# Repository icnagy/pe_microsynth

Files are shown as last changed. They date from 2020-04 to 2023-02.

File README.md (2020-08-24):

# PE Microsynth / Clef B30

Redrawn in KiCad.

Practical Electronics June 1982
MICROSYNTH Part 1 by A.R. Bradford MSc page 18

Practical Electronics July 1982
MICROSYNTH Part 2 by A.R. Bradford MSc page 38

Practical Electronics August 1982
MICROSYNTH Part 3 by A.R.Bradford MSc page 36

## Schematics

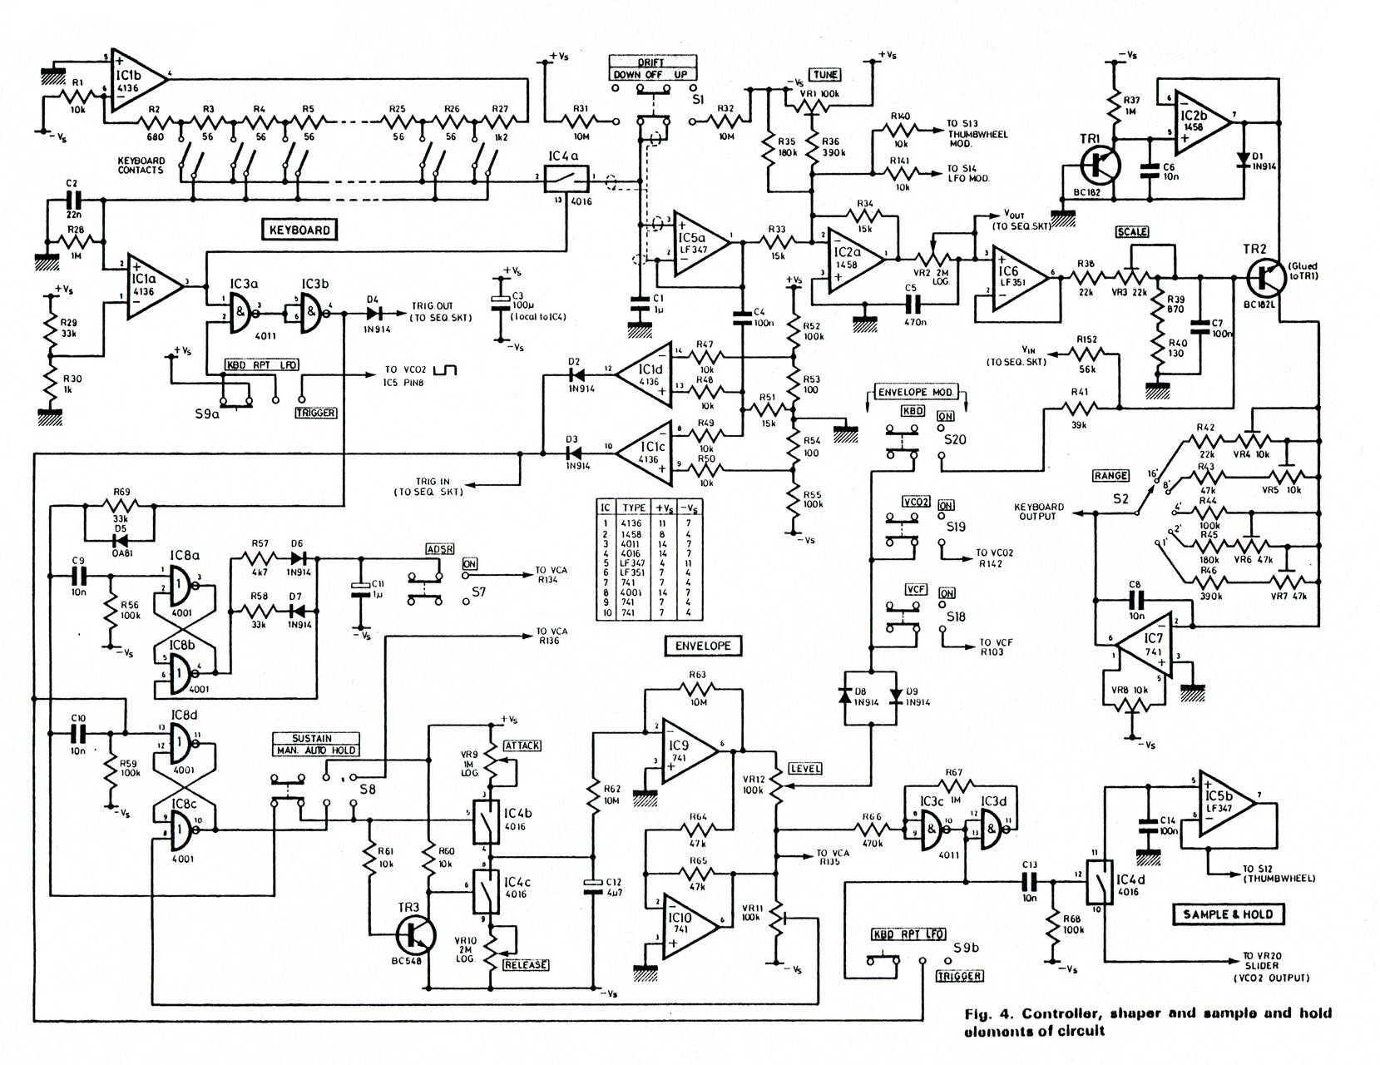
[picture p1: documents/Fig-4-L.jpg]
Figure 4. Controller, shaper and sample and hold elements of circuit

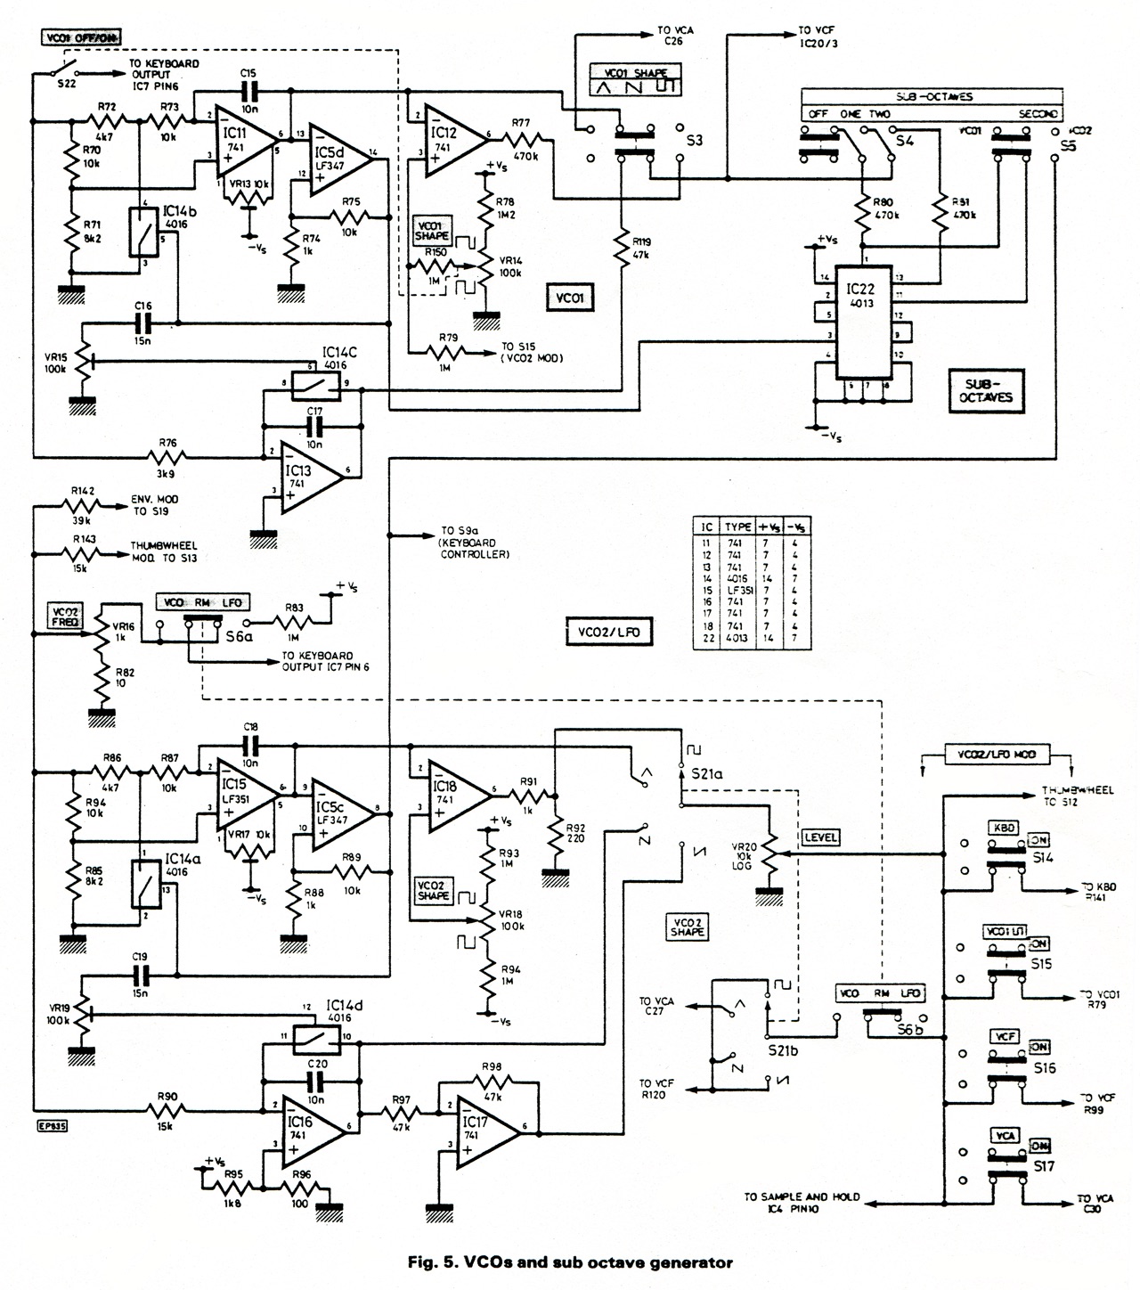
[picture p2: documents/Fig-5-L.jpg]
Figure 5. VCOs and sub octave generator

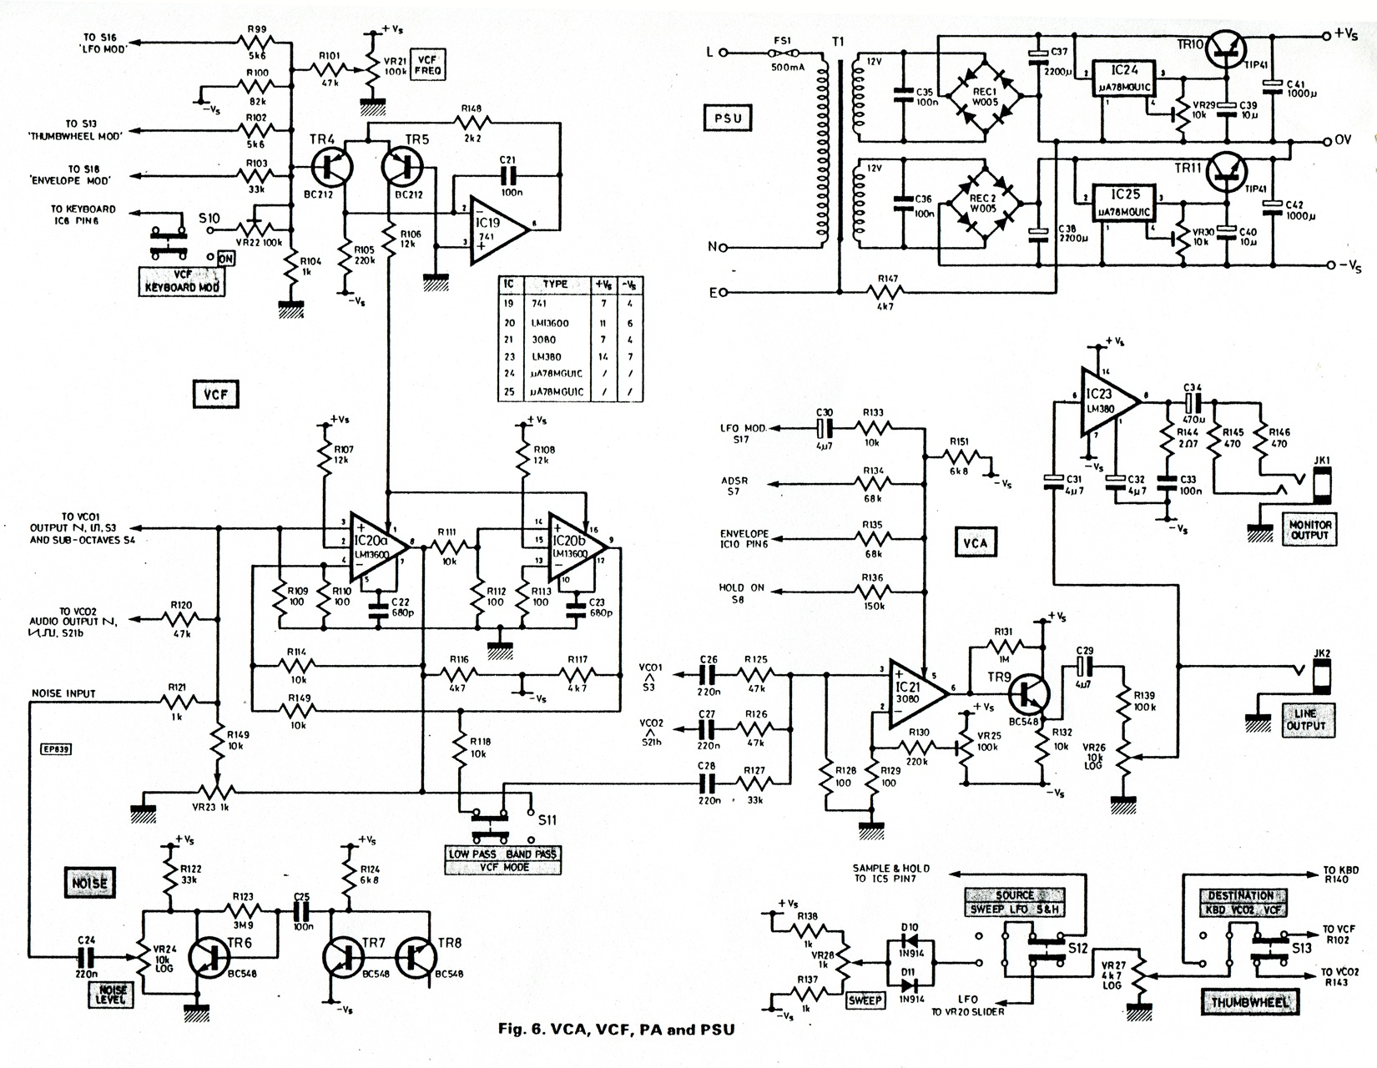
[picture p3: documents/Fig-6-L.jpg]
Figure 6. VCA, VCF, PA and PSU


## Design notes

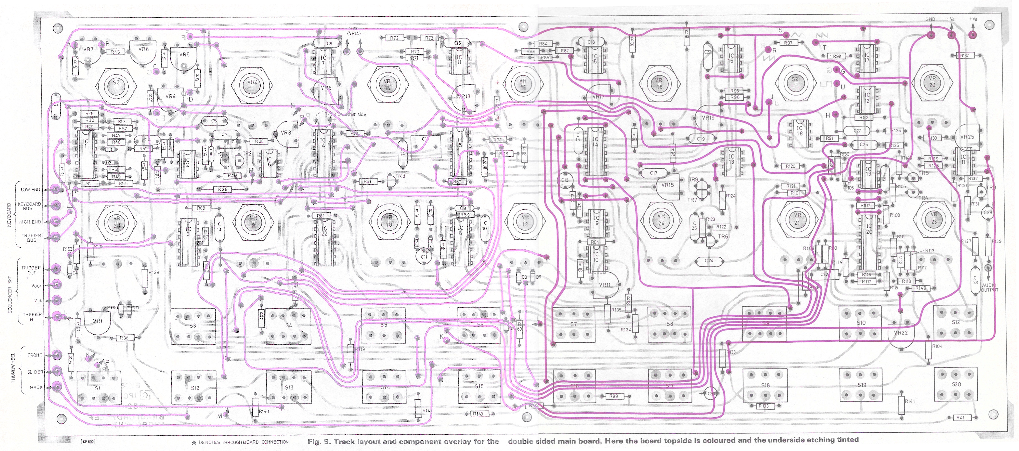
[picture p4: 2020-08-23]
documents/pe-micro-pcb.jpg

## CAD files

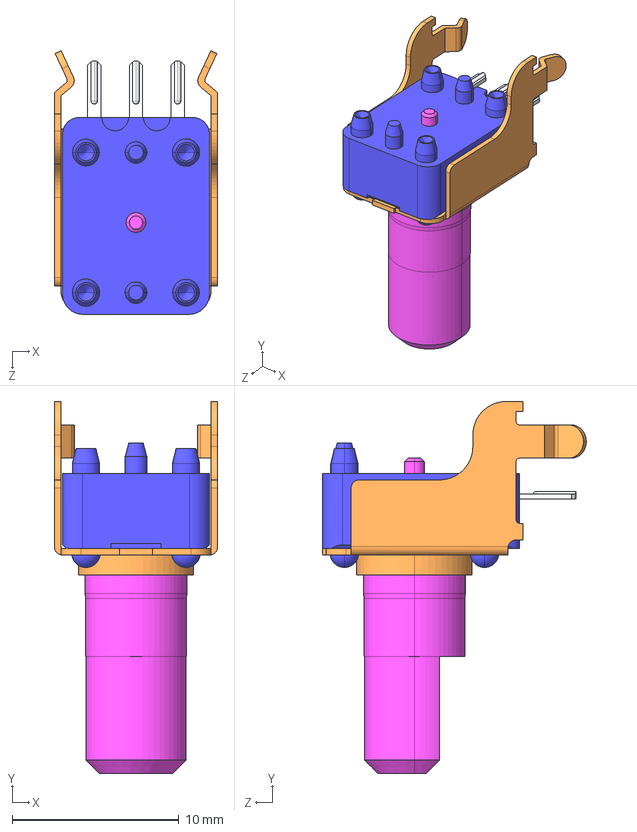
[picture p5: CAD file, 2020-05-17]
3dmodels/RK09K1110B1V.STEP
9.80 x 22.3 x 15.8 mm

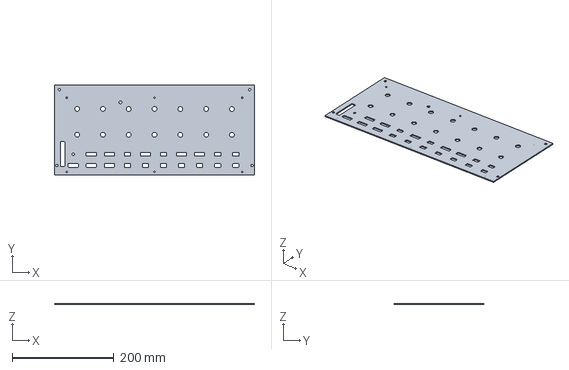
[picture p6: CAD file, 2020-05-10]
3dmodels/pe-microsynthv3.stp
393.7 x 177.8 x 2.00 mm

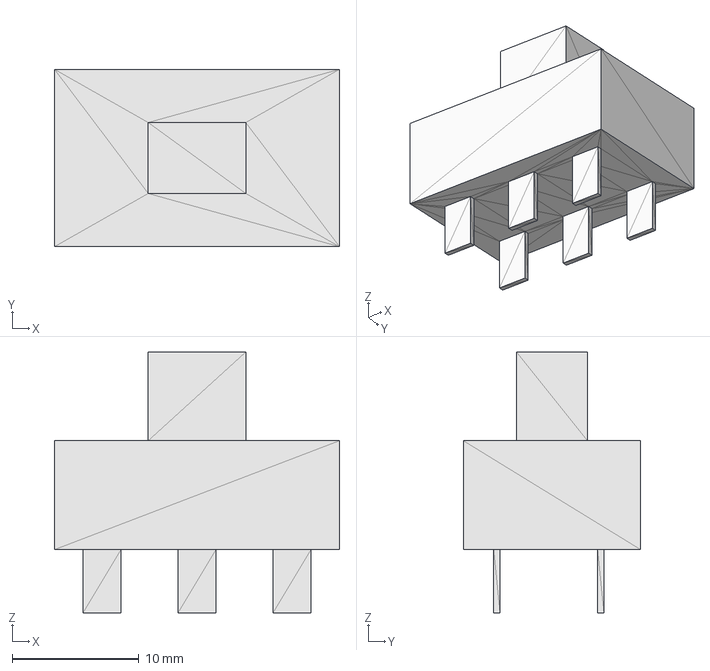
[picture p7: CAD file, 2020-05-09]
3dmodels/dpdt-tayda.step
22.5 x 14.0 x 20.6 mm

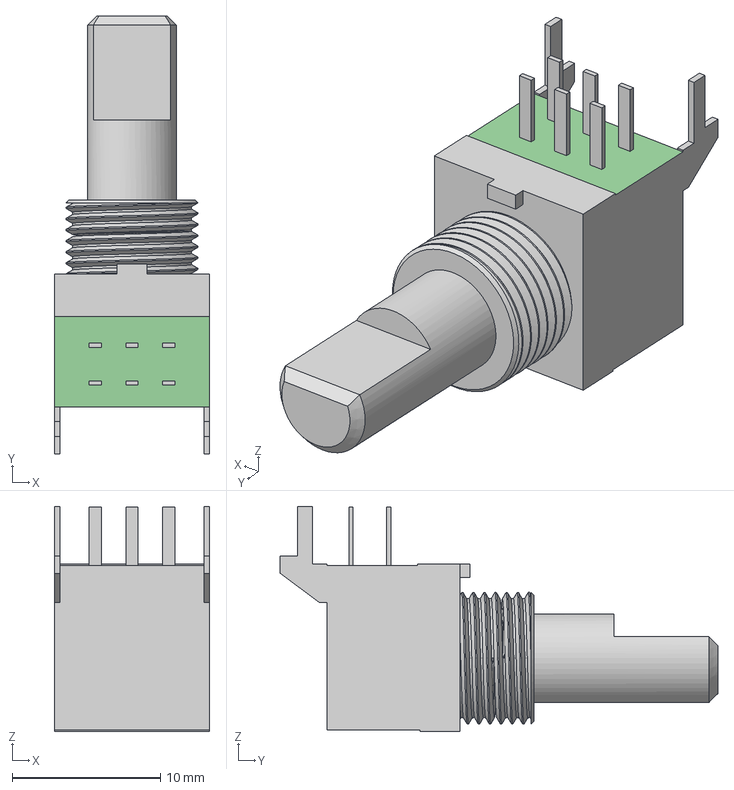
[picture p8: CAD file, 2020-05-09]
3dmodels/ALPS RK09L v3.step
10.5 x 29.6 x 15.2 mm

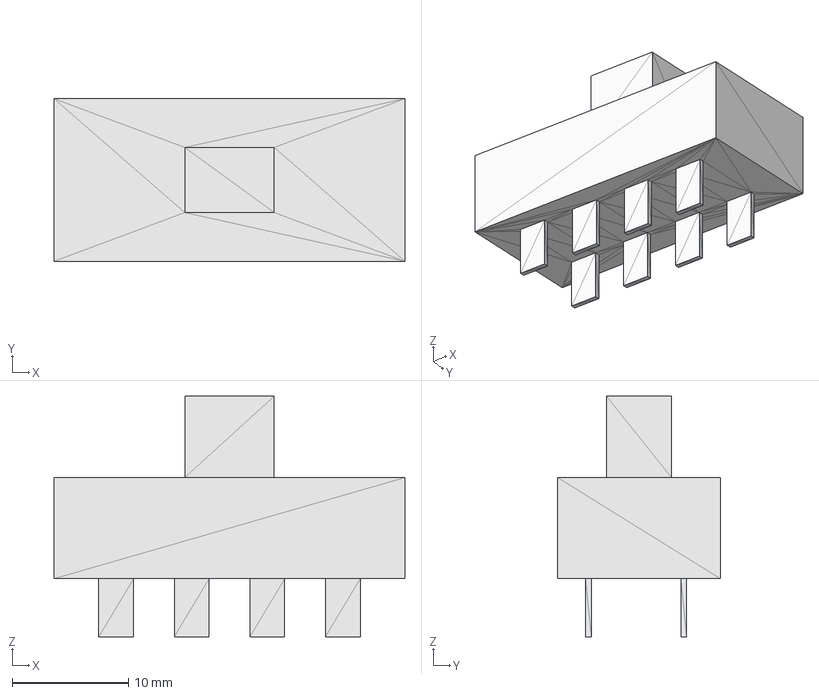
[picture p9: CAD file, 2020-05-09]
3dmodels/dp3t-tayda.step
30.2 x 14.0 x 20.7 mm

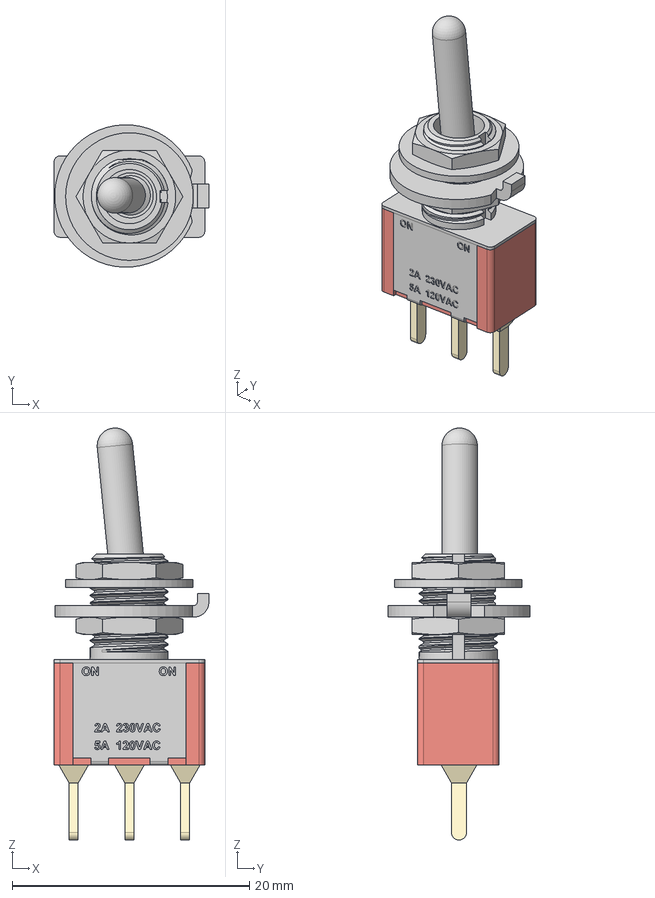
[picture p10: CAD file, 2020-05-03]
3dmodels/RS-PRO Schalter v5.step
13.1 x 12.0 x 34.7 mm
Hebel
Scheibe
Mutter
Scheibe (1)
Mutter (1)
Stifte
Gewinde

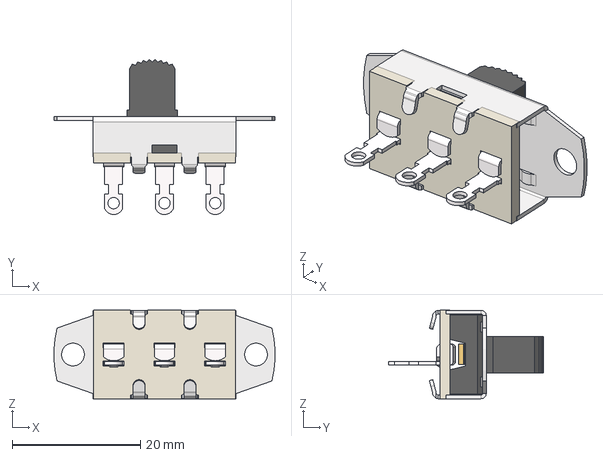
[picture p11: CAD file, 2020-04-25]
3dmodels/GF-624-6014_3D MODEL.stp
34.5 x 24.2 x 13.8 mm

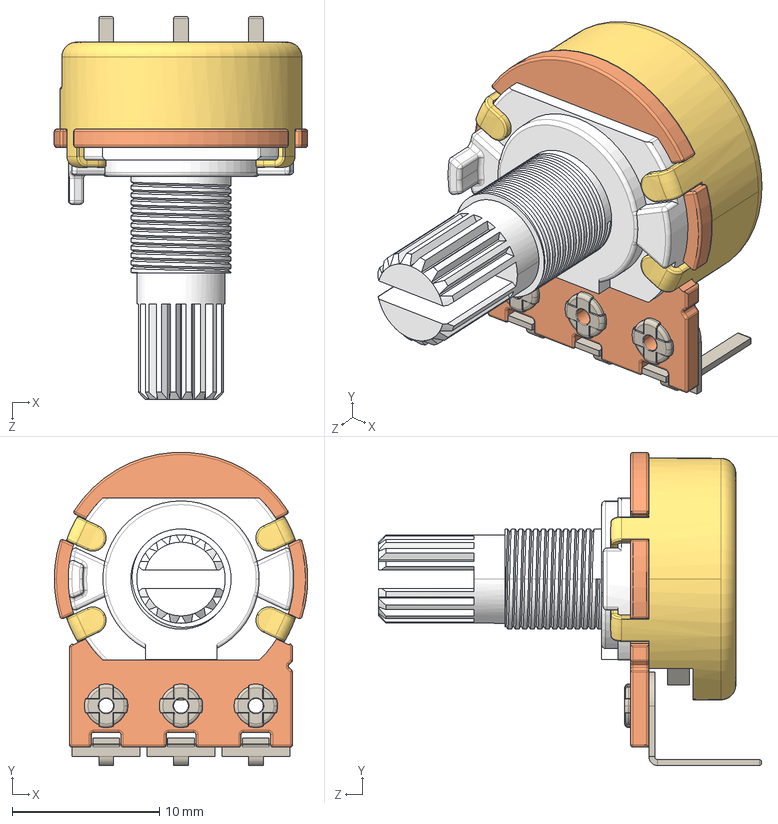
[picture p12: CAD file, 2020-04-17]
3dmodels/Standard Potentiometer - Vertical (No Value).STEP
17.2 x 21.2 x 26.0 mm

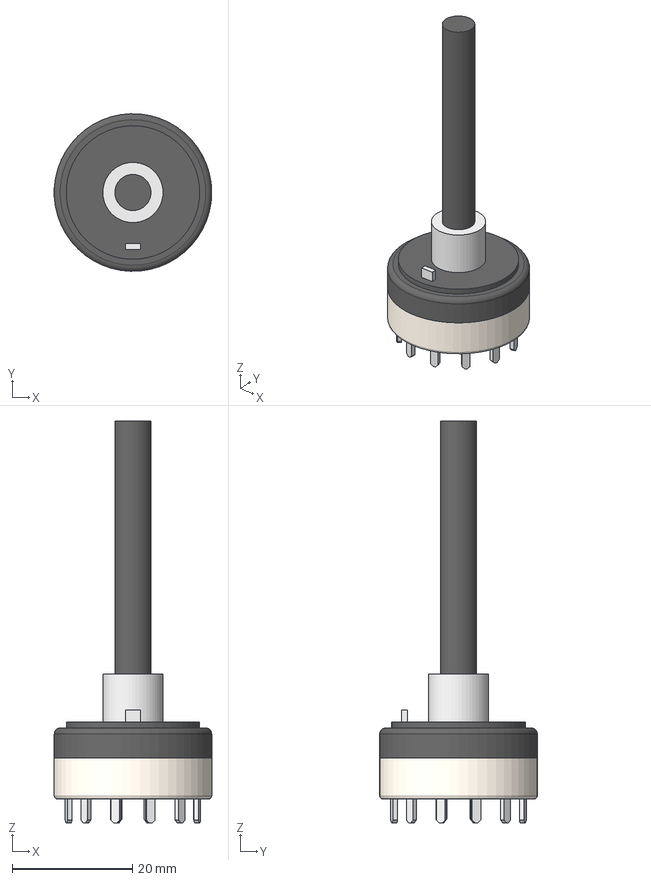
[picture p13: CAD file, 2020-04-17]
3dmodels/Stufenschalter 2x6.step
26.2 x 26.2 x 66.8 mm
Sketch
Circle
Zylinder003
Zylinder004
Zylinder002
Würfel

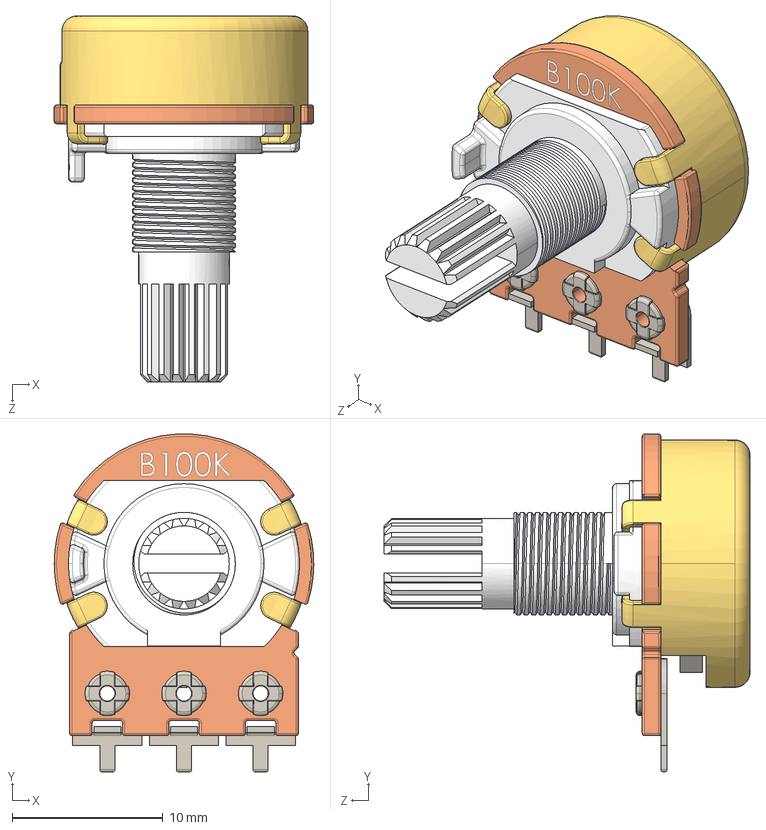
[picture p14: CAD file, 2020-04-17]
3dmodels/Standard Potentiometer - Horizontal (100K).STEP
17.2 x 22.4 x 24.3 mm

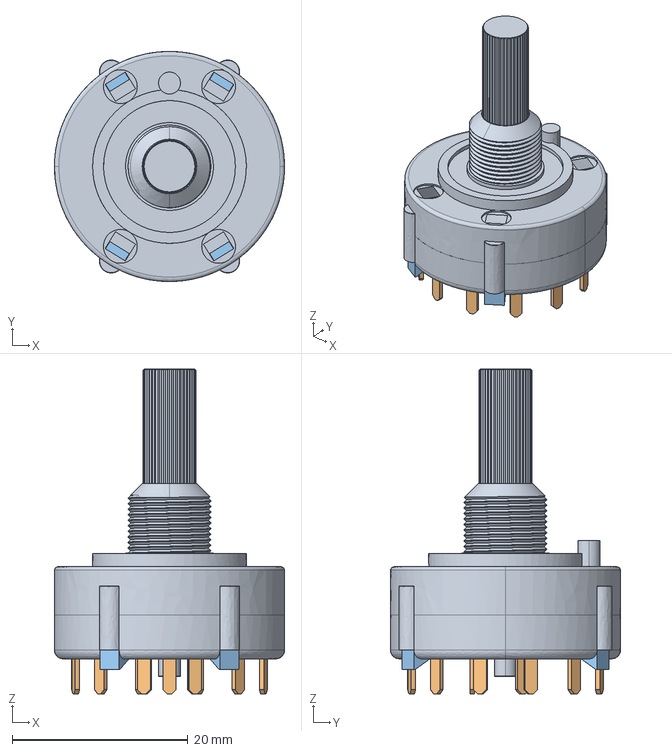
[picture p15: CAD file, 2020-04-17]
3dmodels/Rotary switch 3P4T.step
26.2 x 26.2 x 37.0 mm

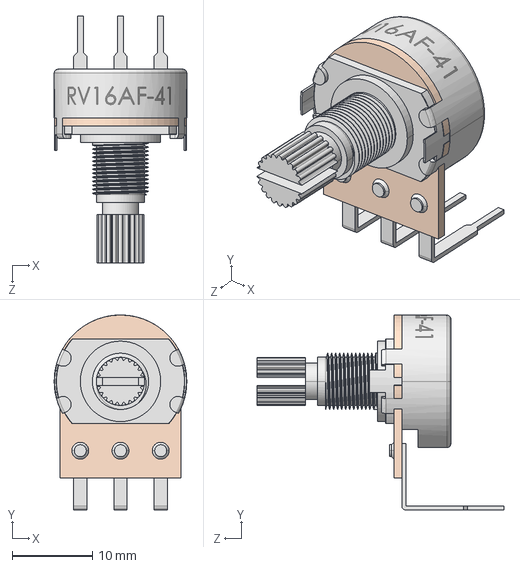
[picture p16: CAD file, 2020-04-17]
3dmodels/potentiometer(RV16AF-41).STEP
16.5 x 24.2 x 30.7 mm

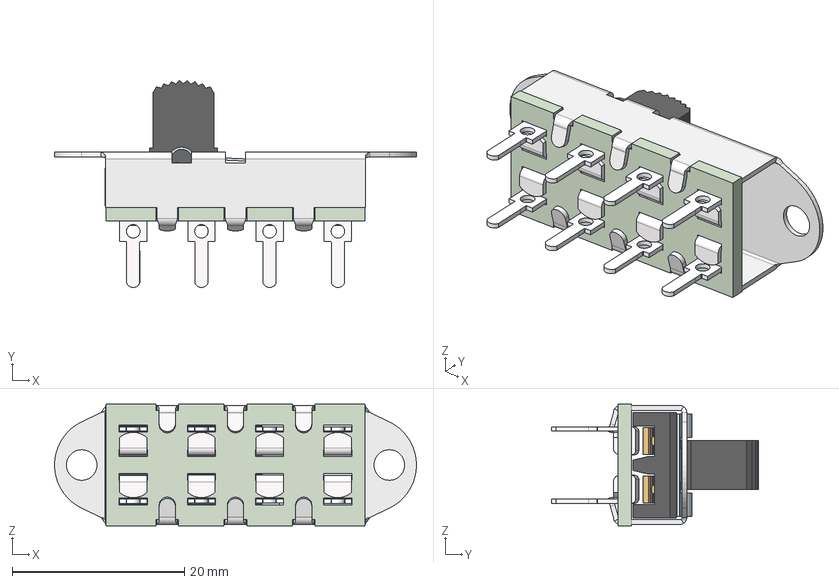
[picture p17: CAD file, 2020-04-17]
3dmodels/G-1128S-1110_3D MODEL.stp
42.1 x 24.0 x 14.1 mm

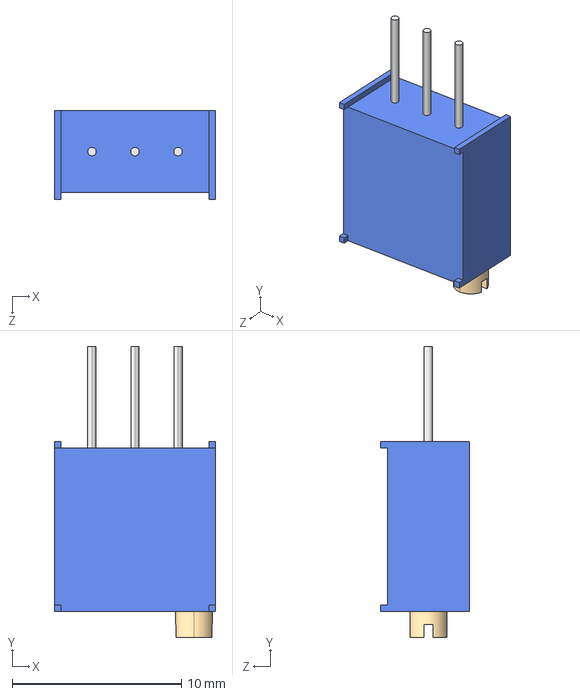
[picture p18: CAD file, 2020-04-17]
3dmodels/TRIMER_POT.STEP
9.52 x 17.2 x 5.23 mm

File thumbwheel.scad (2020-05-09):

$fa = 1;
$fs = 0.2;

pot_shaft_radius = 3;
mod_wheel_radius = 25;
mod_wheel_width = 4;

//An involute spur gear, with reasonable defaults for all the parameters.
//Normally, you should just choose the first 4 parameters, and let the rest be default values.
//Meshing gears must match in mm_per_tooth, pressure_angle, and twist,
//and be separated by the sum of their pitch radii, which can be found with pitch_radius().
module gear (
	mm_per_tooth    = 3,    //this is the "circular pitch", the circumference of the pitch circle divided by the number of teeth
	number_of_teeth = 11,   //total number of teeth around the entire perimeter
	thickness       = 6,    //thickness of gear in mm
	hole_diameter   = 3,    //diameter of the hole in the center, in mm
	twist           = 0,    //teeth rotate this many degrees from bottom of gear to top.  360 makes the gear a screw with each thread going around once
	teeth_to_hide   = 0,    //number of teeth to delete to make this only a fraction of a circle
	pressure_angle  = 28,   //Controls how straight or bulged the tooth sides are. In degrees.
	clearance       = 0.0,  //gap between top of a tooth on one gear and bottom of valley on a meshing gear (in millimeters)
	backlash        = 0.0   //gap between two meshing teeth, in the direction along the circumference of the pitch circle
) {
	pi = 3.1415926;
	p  = 12.5; //mm_per_tooth * number_of_teeth / pi / 2;  //radius of pitch circle
	c  = p + mm_per_tooth / pi - clearance;        //radius of outer circle
	b  = p*cos(pressure_angle);                    //radius of base circle
	r  = p-(c-p)-clearance;                        //radius of root circle
	t  = mm_per_tooth/2-backlash/2;                //tooth thickness at pitch circle
	k  = -iang(b, p) - t/2/p/pi*180;              //angle to where involute meets base circle on each side of tooth
		difference() {
			for (i = [0:number_of_teeth-teeth_to_hide-1] )
				rotate([0,0,i*360/number_of_teeth])
					linear_extrude(height = thickness, center = true, convexity = 10, twist = twist)
						polygon(
							points=[
								[0, -hole_diameter/10],
								polar(r, -181/number_of_teeth),
								polar(r, r<b ? k : -180/number_of_teeth),
								q7(0/5,r,b,c,k, 1),q7(1/5,r,b,c,k, 1),q7(2/5,r,b,c,k, 1),q7(3/5,r,b,c,k, 1),q7(4/5,r,b,c,k, 1),q7(5/5,r,b,c,k, 1),
								q7(5/5,r,b,c,k,-1),q7(4/5,r,b,c,k,-1),q7(3/5,r,b,c,k,-1),q7(2/5,r,b,c,k,-1),q7(1/5,r,b,c,k,-1),q7(0/5,r,b,c,k,-1),
								polar(r, r<b ? -k : 180/number_of_teeth),
								polar(r, 181/number_of_teeth)
							],
 							paths=[[0,1,2,3,4,5,6,7,8,9,10,11,12,13,14,15,16]]
						);
			cylinder(h=2*thickness+1, r=hole_diameter/2, center=true, $fn=20);
		}
	
};	
//these 4 functions are used by gear
function polar(r,theta)   = r*[sin(theta), cos(theta)];                            //convert polar to cartesian coordinates
function iang(r1,r2)      = sqrt((r2/r1)*(r2/r1) - 1)/3.1415926*180 - acos(r1/r2); //unwind a string this many degrees to go from radius r1 to radius r2
function q7(f,r,b,r2,t,s) = q6(b,s,t,(1-f)*max(b,r)+f*r2);                         //radius a fraction f up the curved side of the tooth 
function q6(b,s,t,d)      = polar(d,s*(iang(b,d)+t));                              //point at radius d on the involute curve

//These 5 functions let the user find the derived dimensions of the gear.
//A gear fits within a circle of radius outer_radius, and two gears should have
//their centers separated by the sum of their pictch_radius.
function circular_pitch  (mm_per_tooth=3) = mm_per_tooth;                     //tooth density expressed as "circular pitch" in millimeters
function diametral_pitch (mm_per_tooth=3) = 3.1415926 / mm_per_tooth;         //tooth density expressed as "diametral pitch" in teeth per millimeter
function module_value    (mm_per_tooth=3) = mm_per_tooth / pi;                //tooth density expressed as "module" or "modulus" in millimeters
function pitch_radius    (mm_per_tooth=3,number_of_teeth=11) = mm_per_tooth * number_of_teeth / 3.1415926 / 2;
function outer_radius    (mm_per_tooth=3,number_of_teeth=11,clearance=0.1)    //The gear fits entirely within a cylinder of this radius.
	= mm_per_tooth*(1+number_of_teeth/2)/3.1415926  - clearance;              



rotate(150)
translate([0,0,-3])
difference() {
color([0.22,0,0])
gear(
	1, //	mm_per_tooth
	80,//number_of_teeth
	2, //thickness
	2.8, //hole_diameter
	0, //twist
	0, //teeth_to_hide
	33,//pressure_angle
	0.2,//clearance
	0.3//backlash
);
    translate([17,0,0]) color([0.75,0.75,0.75]) cube([25,30,3], center = true);
  }

rotate(-150)
difference() {

gear(
	1, //	mm_per_tooth
	80,//number_of_teeth
	2, //thickness
	2.8, //hole_diameter
	0, //twist
	0, //teeth_to_hide
	33,//pressure_angle
	0.2,//clearance
	0.3//backlash
);
    translate([17,0,0]) color([0.75,0.75,0.75]) cube([25,30,3], center = true);
  }

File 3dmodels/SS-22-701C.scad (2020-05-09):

linear_extrude(8.6) square([22.5,14], center= true);

translate([0,0,8.6]) linear_extrude(7) square([7.7,5.6], center=true);

rotate([90,0,0]) translate([7.5,-2.5,-4.1]) linear_extrude(0.5) square([3,5], center=true);

rotate([90,0,0]) translate([7.5,-2.5,4.1]) linear_extrude(0.5) square([3,5], center=true);


rotate([90,0,0]) translate([0,-2.5,-4.1]) linear_extrude(0.5) square([3,5], center=true);

rotate([90,0,0]) translate([0,-2.5,4.1]) linear_extrude(0.5) square([3,5], center=true);

rotate([90,0,0]) translate([-7.5,-2.5,-4.1]) linear_extrude(0.5) square([3,5], center=true);

rotate([90,0,0]) translate([-7.5,-2.5,4.1]) linear_extrude(0.5) square([3,5], center=true);

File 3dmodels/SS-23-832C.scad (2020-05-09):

union(){linear_extrude(8.7) square([30.2,14], center= true);

translate([0,0,8.7]) linear_extrude(7) square([7.7,5.6], center=true);

rotate([90,0,0]) translate([9.75,-2.5,-4.1]) linear_extrude(0.5) square([3,5], center=true);

rotate([90,0,0]) translate([9.75,-2.5,4.1]) linear_extrude(0.5) square([3,5], center=true);


rotate([90,0,0]) translate([3.25,-2.5,-4.1]) linear_extrude(0.5) square([3,5], center=true);

rotate([90,0,0]) translate([3.25,-2.5,4.1]) linear_extrude(0.5) square([3,5], center=true);


rotate([90,0,0]) translate([-3.25,-2.5,-4.1]) linear_extrude(0.5) square([3,5], center=true);

rotate([90,0,0]) translate([-3.25,-2.5,4.1]) linear_extrude(0.5) square([3,5], center=true);


rotate([90,0,0]) translate([-9.75,-2.5,-4.1]) linear_extrude(0.5) square([3,5], center=true);

rotate([90,0,0]) translate([-9.75,-2.5,4.1]) linear_extrude(0.5) square([3,5], center=true);
}

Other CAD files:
3dmodels/Standard Potentiometer - Vertical (100K).STEP
3dmodels/Standard Potentiometer - Horizontal (No Value).STEP
3dmodels/DP3T Slide Switch.step
3dmodels/pe-microsynthv3.dxf

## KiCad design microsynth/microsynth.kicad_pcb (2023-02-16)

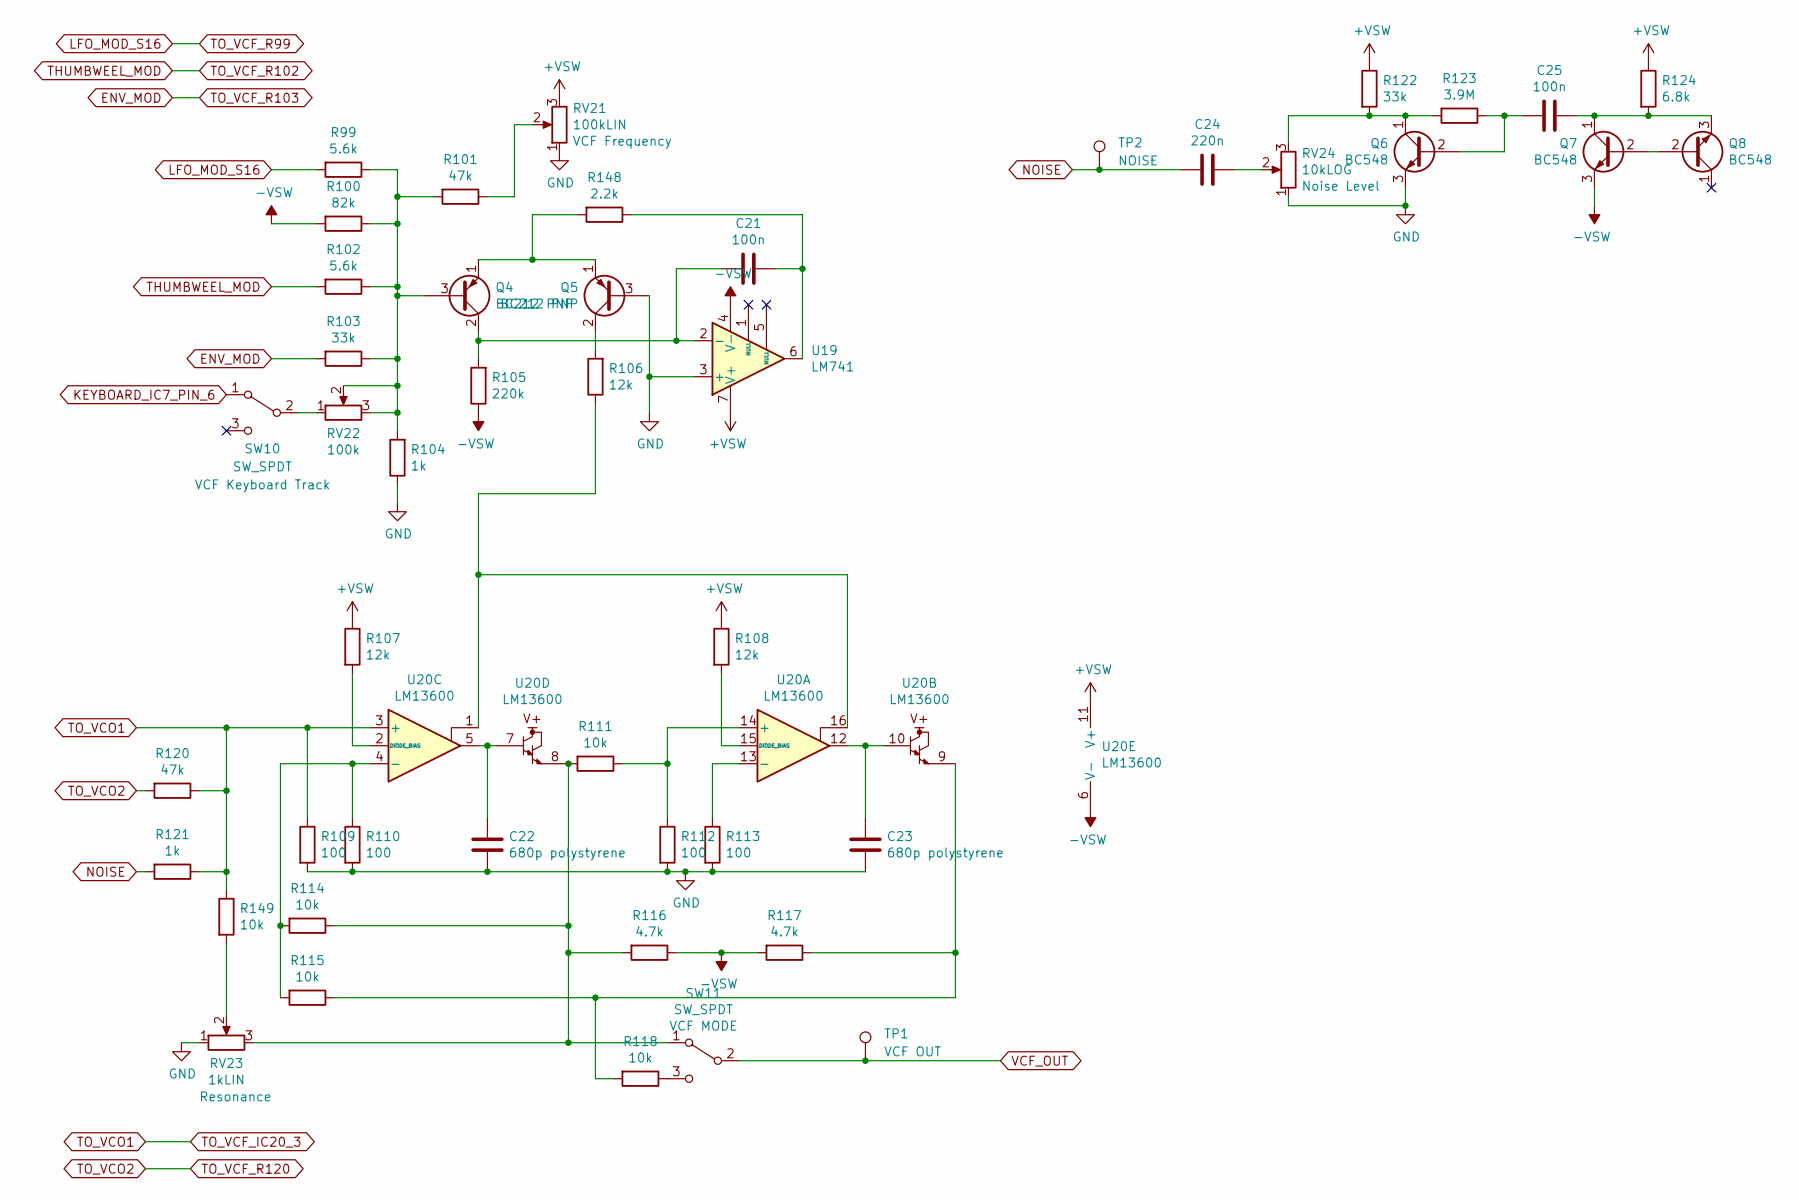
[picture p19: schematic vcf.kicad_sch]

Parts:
C21, C25: 100n; C_Rect_L7.2mm_W2.5mm_P5.00mm_FKS2_FKP2_MKS2_MKP2
C22, C23: 680p polystyrene; C_Axial_L12.0mm_D6.5mm_P15.00mm_Horizontal
C24: 220n; C_Rect_L7.2mm_W2.5mm_P5.00mm_FKS2_FKP2_MKS2_MKP2
Q4, Q5: BC212 PNP; TO-92L_Inline_Wide
Q6, Q7, Q8: BC548; TO-92L_Inline_Wide
R99, R102: 5.6k; R_Axial_DIN0207_L6.3mm_D2.5mm_P10.16mm_Horizontal
R100: 82k; R_Axial_DIN0207_L6.3mm_D2.5mm_P10.16mm_Horizontal
R101, R120: 47k; R_Axial_DIN0207_L6.3mm_D2.5mm_P10.16mm_Horizontal
R103, R122: 33k; R_Axial_DIN0207_L6.3mm_D2.5mm_P10.16mm_Horizontal
R104, R121: 1k; R_Axial_DIN0207_L6.3mm_D2.5mm_P10.16mm_Horizontal
R105: 220k; R_Axial_DIN0207_L6.3mm_D2.5mm_P10.16mm_Horizontal
R106, R107, R108: 12k; R_Axial_DIN0207_L6.3mm_D2.5mm_P10.16mm_Horizontal
R109, R110, R112, R113: 100; R_Axial_DIN0207_L6.3mm_D2.5mm_P10.16mm_Horizontal
R111, R114, R115, R118, R149: 10k; R_Axial_DIN0207_L6.3mm_D2.5mm_P10.16mm_Horizontal
R116, R117: 4.7k; R_Axial_DIN0207_L6.3mm_D2.5mm_P10.16mm_Horizontal
R123: 3.9M; R_Axial_DIN0207_L6.3mm_D2.5mm_P10.16mm_Horizontal
R124: 6.8k; R_Axial_DIN0207_L6.3mm_D2.5mm_P10.16mm_Horizontal
R148: 2.2k; R_Axial_DIN0207_L6.3mm_D2.5mm_P10.16mm_Horizontal
RV21: 100kLIN; Pot_16mm_NoDet_RV16AF-4A
RV22: 100k; Potentiometer_Bourns_3296W_Vertical
RV23: 1kLIN; Pot_16mm_NoDet_RV16AF-4A
RV24: 10kLOG; Pot_16mm_NoDet_RV16AF-4A
SW10, SW11: SW_SPDT; 11-SS-22-701C
TP1: VCF OUT; TestPoint_Pad_D2.0mm
TP2: NOISE; TestPoint_Pad_D2.0mm
U19: LM741; DIP-8_W7.62mm_LongPads
U20: LM13600; DIP-16_W7.62mm_LongPads

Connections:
+VSW: R107.1, R108.1, R122.1, R124.1, RV21.3, U19.7 (V+), U20.11 (V+); also elsewhere on the board
-VSW: Q7.3 (E), R100.2, R105.1, R116.1, R117.2, U19.4 (V-), U20.6 (V-); also elsewhere on the board
ENV_MOD: R103.2; also elsewhere on the board
GND: C22.2, C23.2, Q5.3 (B), Q6.3 (E), R104.1, R109.2, R110.2, R112.2, R113.2, RV21.1, RV23.1, RV24.1, U19.3 (+); also elsewhere on the board
KEYBOARD_IC7_PIN_6: SW10.1 (A); also elsewhere on the board
LFO_MOD_S16: R99.2; also elsewhere on the board
NOISE: C24.2, R121.2, TP2.1
unnamed: C21.1, R148.1, U19.6
unnamed: C21.2, Q4.2 (C), R105.2, U19.2 (-)
unnamed: C22.1, U20.5, U20.7
unnamed: C23.1, U20.10, U20.12
unnamed: C24.1, RV24.2
unnamed: C25.1, Q7.1 (C), Q8.3 (E), R124.2
unnamed: C25.2, Q6.2 (B), R123.1
unnamed: Q4.1 (E), Q5.1 (E), R148.2
unnamed: Q4.3 (B), R99.1, R100.1, R101.2, R102.1, R103.1, R104.2, RV22.2, RV22.3
unnamed: Q5.2 (C), R106.2
unnamed: Q6.1 (C), R122.2, R123.2, RV24.3
unnamed: Q7.2 (B), Q8.2 (B)
unnamed: R101.1, RV21.2
unnamed: R106.1, U20.1, U20.16
unnamed: R107.2, U20.2 (DIODE_BIAS)
unnamed: R108.2, U20.15 (DIODE_BIAS)
unnamed: R110.1, R114.2, R115.2, U20.4 (-)
unnamed: R111.1, R112.1, U20.14 (+)
unnamed: R111.2, R114.1, R116.2, RV23.3, SW11.1 (A), U20.8
unnamed: R113.1, U20.13 (-)
unnamed: R115.1, R117.1, R118.2, U20.9
unnamed: R118.1, SW11.3 (C)
unnamed: R149.2, RV23.2
unnamed: RV22.1, SW10.2 (B)
THUMBWEEL_MOD: R102.2; also elsewhere on the board
TO_VCF_IC20_3: R109.1, R120.1, R121.1, R149.1, U20.3 (+); also elsewhere on the board
TO_VCF_R120: R120.2; also elsewhere on the board
VCF_OUT: SW11.2 (B), TP1.1; also elsewhere on the board

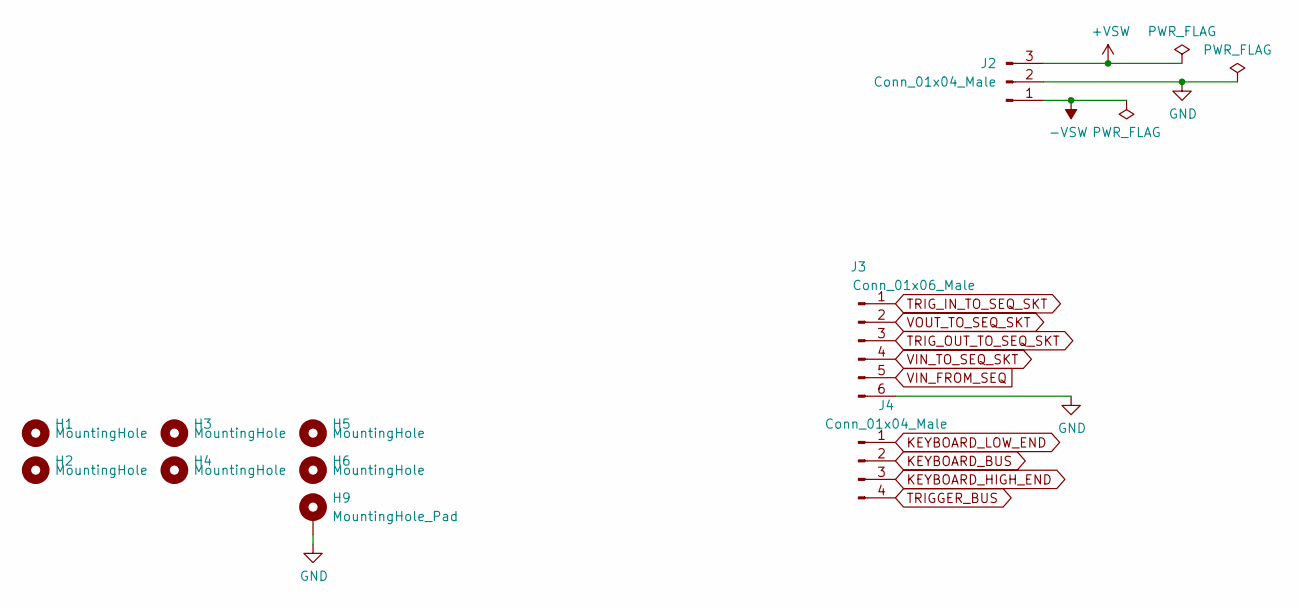
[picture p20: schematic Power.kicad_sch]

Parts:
H1, H2, H3, H4, H5, H6: MountingHole; MountingHole_3.2mm_M3
H9: MountingHole_Pad; PinHeader_1x01_P2.54mm_Vertical
J2: Conn_01x04_Male; PhoenixContact_MSTBA_2,5_3-G_1x03_P5.00mm_Horizontal
J3: Conn_01x06_Male; PinHeader_1x06_P2.54mm_Vertical
J4: Conn_01x04_Male; PinHeader_1x04_P2.54mm_Vertical

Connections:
+VSW: J2.3; also elsewhere on the board
-VSW: J2.1; also elsewhere on the board
GND: H9.1, J2.2, J3.6; also elsewhere on the board
KEYBOARD_BUS: J4.2; also elsewhere on the board
KEYBOARD_HIGH_END: J4.3; also elsewhere on the board
KEYBOARD_LOW_END: J4.1; also elsewhere on the board
TRIGGER_BUS: J4.4; also elsewhere on the board
TRIG_IN_TO_SEQ_SKT: J3.1; also elsewhere on the board
TRIG_OUT_TO_SEQ_SKT: J3.3; also elsewhere on the board
VIN_FROM_SEQ: J3.5; also elsewhere on the board
VIN_TO_SEQ_SKT: J3.4; also elsewhere on the board
VOUT_TO_SEQ_SKT: J3.2; also elsewhere on the board

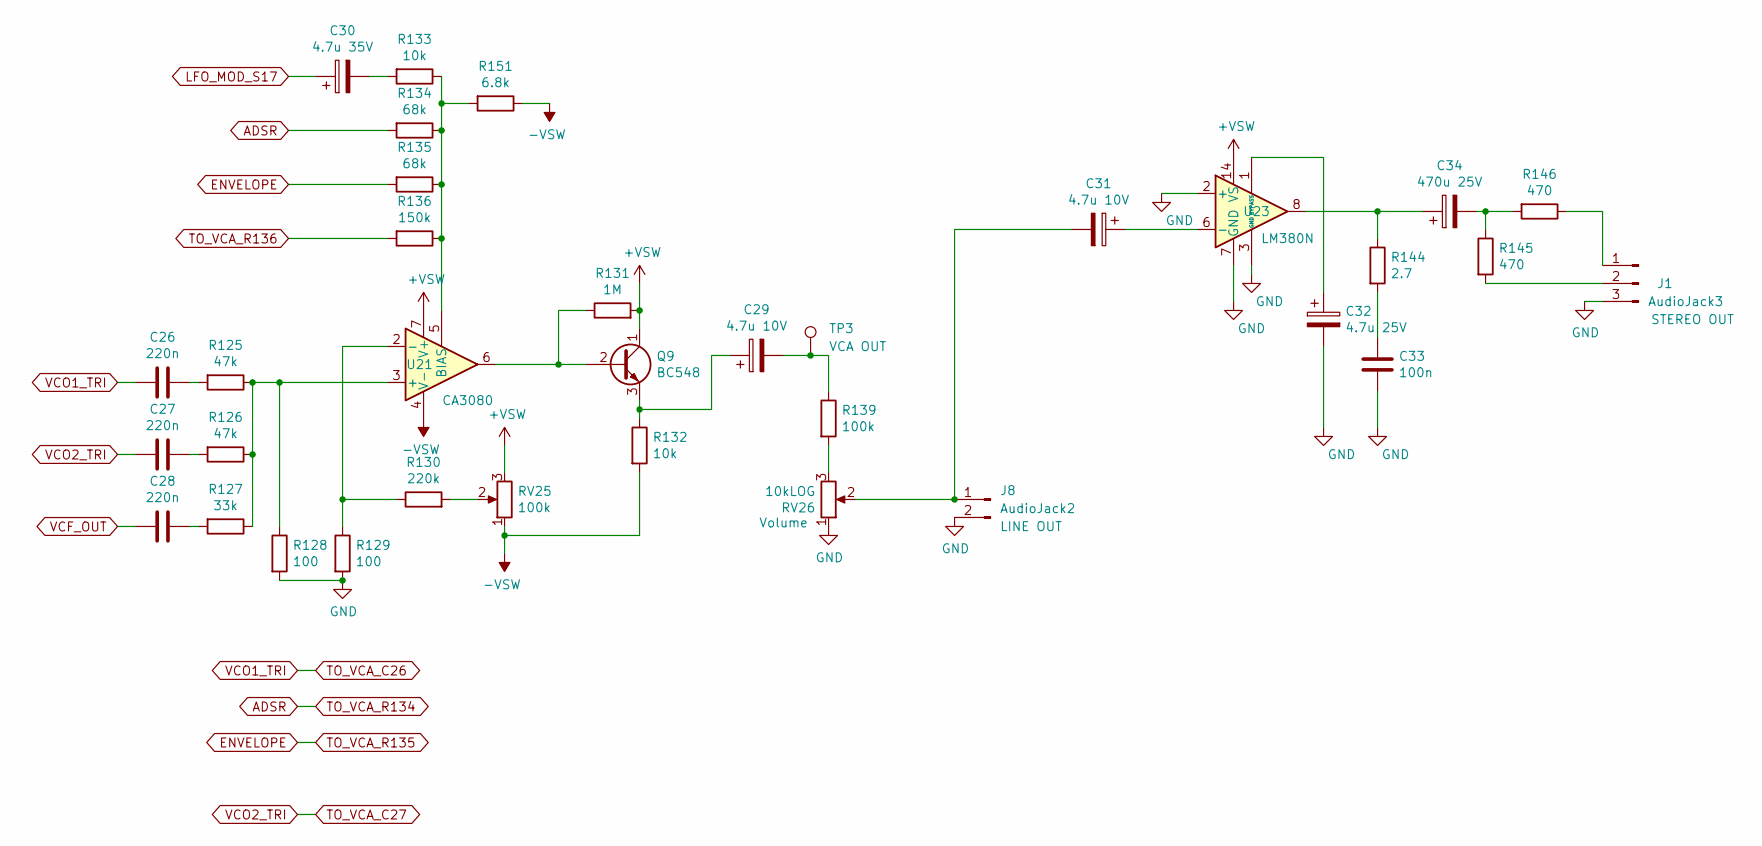
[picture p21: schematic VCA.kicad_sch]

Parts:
C26, C27, C28: 220n; C_Rect_L7.2mm_W2.5mm_P5.00mm_FKS2_FKP2_MKS2_MKP2
C29, C31: 4.7u 10V; CP_Radial_D5.0mm_P2.50mm
C30: 4.7u 35V; CP_Radial_D5.0mm_P2.50mm
C32: 4.7u 25V; CP_Radial_D5.0mm_P2.50mm
C33: 100n; C_Rect_L7.2mm_W2.5mm_P5.00mm_FKS2_FKP2_MKS2_MKP2
C34: 470u 25V; CP_Radial_D10.0mm_P5.00mm
J1: AudioJack3; PinHeader_1x03_P2.54mm_Vertical
J8: AudioJack2; PinHeader_1x02_P2.54mm_Vertical
Q9: BC548; TO-92L_Inline_Wide
R125, R126: 47k; R_Axial_DIN0207_L6.3mm_D2.5mm_P10.16mm_Horizontal
R127: 33k; R_Axial_DIN0207_L6.3mm_D2.5mm_P10.16mm_Horizontal
R128, R129: 100; R_Axial_DIN0207_L6.3mm_D2.5mm_P10.16mm_Horizontal
R130: 220k; R_Axial_DIN0207_L6.3mm_D2.5mm_P10.16mm_Horizontal
R131: 1M; R_Axial_DIN0207_L6.3mm_D2.5mm_P10.16mm_Horizontal
R132, R133: 10k; R_Axial_DIN0207_L6.3mm_D2.5mm_P10.16mm_Horizontal
R134, R135: 68k; R_Axial_DIN0207_L6.3mm_D2.5mm_P10.16mm_Horizontal
R136: 150k; R_Axial_DIN0207_L6.3mm_D2.5mm_P10.16mm_Horizontal
R139: 100k; R_Axial_DIN0207_L6.3mm_D2.5mm_P10.16mm_Horizontal
R144: 2.7; R_Axial_DIN0207_L6.3mm_D2.5mm_P10.16mm_Horizontal
R145, R146: 470; R_Axial_DIN0207_L6.3mm_D2.5mm_P10.16mm_Horizontal
R151: 6.8k; R_Axial_DIN0207_L6.3mm_D2.5mm_P10.16mm_Horizontal
RV25: 100k; Potentiometer_Bourns_3296W_Vertical
RV26: 10kLOG; PinHeader_1x03_P2.54mm_Vertical
TP3: VCA OUT; TestPoint_Pad_D2.0mm
U21: CA3080; DIP-8_W7.62mm_LongPads
U23: LM380N; DIP-14_W7.62mm_LongPads

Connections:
+VSW: Q9.1 (C), R131.2, RV25.3, U21.7 (V+), U23.14 (VS); also elsewhere on the board
-VSW: R132.2, R151.1, RV25.1, U21.4 (V-); also elsewhere on the board
ADSR: R134.2; also elsewhere on the board
ENVELOPE: R135.2; also elsewhere on the board
GND: C32.2, C33.2, J1.3, J8.2, R128.2, R129.2, RV26.1, U23.2 (+), U23.3 (GND), U23.4 (GND), U23.5 (GND), U23.7 (GND), U23.10 (GND), U23.11 (GND), U23.12 (GND); also elsewhere on the board
LFO_MOD_S17: C30.1; also elsewhere on the board
unnamed: C26.1, R125.2
unnamed: C27.2, R126.2
unnamed: C28.2, R127.2
unnamed: C29.1, Q9.3 (E), R132.1
unnamed: C29.2, R139.1, TP3.1
unnamed: C30.2, R133.2
unnamed: C31.1, U23.6 (-)
unnamed: C31.2, J8.1, RV26.2
unnamed: C32.1, U23.1 (BYPASS)
unnamed: C33.1, R144.2
unnamed: C34.1, R144.1, U23.8
unnamed: C34.2, R145.1, R146.2
unnamed: J1.1, R146.1
unnamed: J1.2, R145.2
unnamed: Q9.2 (B), R131.1, U21.6
unnamed: R125.1, R126.1, R127.1, R128.1, U21.3 (+)
unnamed: R129.1, R130.1, U21.2 (-)
unnamed: R130.2, RV25.2
unnamed: R133.1, R134.1, R135.1, R136.1, R151.2, U21.5 (BIAS)
unnamed: R139.2, RV26.3
TO_VCA_C26: C26.2; also elsewhere on the board
TO_VCA_C27: C27.1; also elsewhere on the board
TO_VCA_R136: R136.2; also elsewhere on the board
VCF_OUT: C28.1; also elsewhere on the board

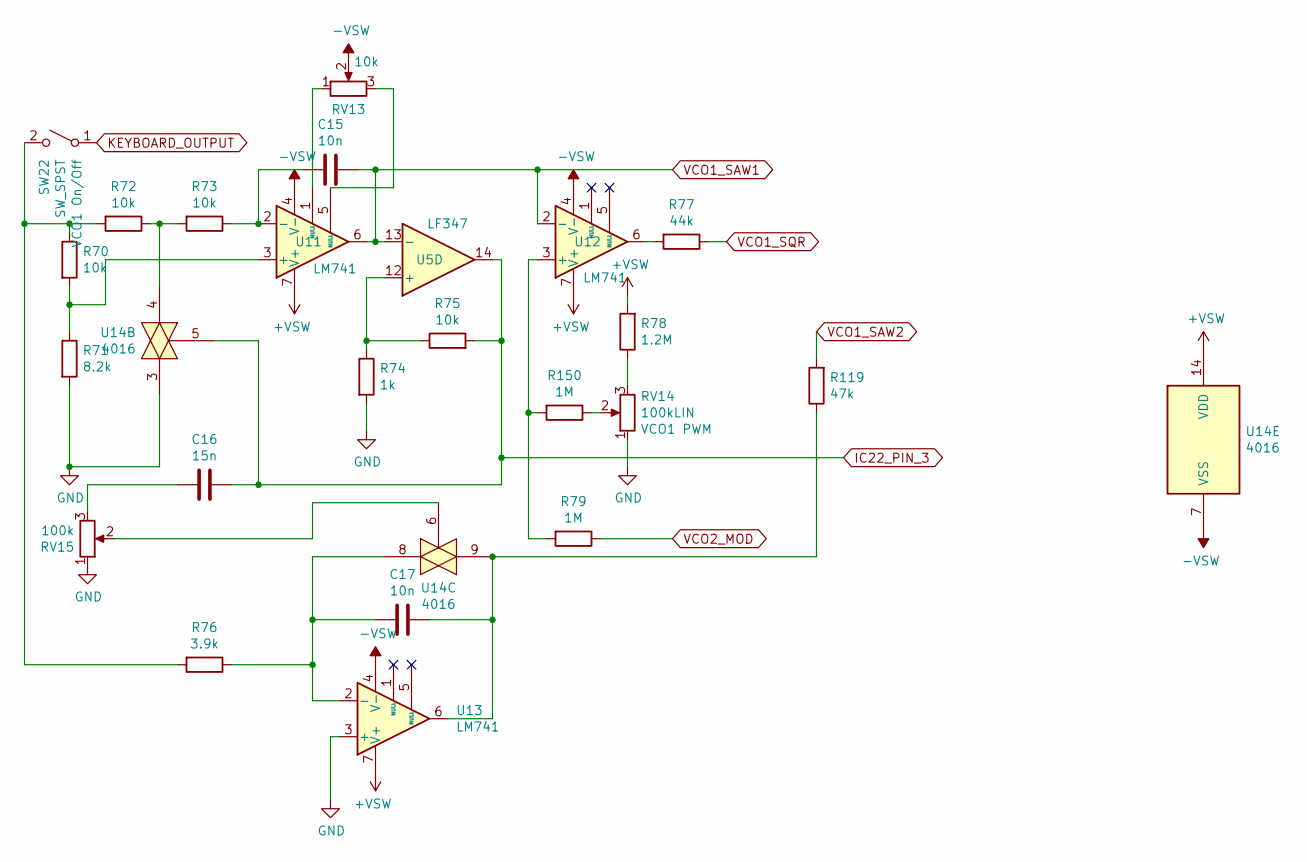
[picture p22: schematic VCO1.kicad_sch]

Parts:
C15, C17: 10n; C_Rect_L7.2mm_W2.5mm_P5.00mm_FKS2_FKP2_MKS2_MKP2
C16: 15n; C_Rect_L7.2mm_W3.5mm_P5.00mm_FKS2_FKP2_MKS2_MKP2
R70, R72, R73, R75: 10k; R_Axial_DIN0207_L6.3mm_D2.5mm_P10.16mm_Horizontal
R71: 8.2k; R_Axial_DIN0207_L6.3mm_D2.5mm_P10.16mm_Horizontal
R74: 1k; R_Axial_DIN0207_L6.3mm_D2.5mm_P10.16mm_Horizontal
R76: 3.9k; R_Axial_DIN0207_L6.3mm_D2.5mm_P10.16mm_Horizontal
R77: 44k; R_Axial_DIN0207_L6.3mm_D2.5mm_P10.16mm_Horizontal
R78: 1.2M; R_Axial_DIN0207_L6.3mm_D2.5mm_P10.16mm_Horizontal
R79, R150: 1M; R_Axial_DIN0207_L6.3mm_D2.5mm_P10.16mm_Horizontal
R119: 47k; R_Axial_DIN0207_L6.3mm_D2.5mm_P10.16mm_Horizontal
RV13: 10k; Potentiometer_Bourns_3296W_Vertical
RV14: 100kLIN; Pot_16mm_NoDet_RV16AF-4A
RV15: 100k; Potentiometer_Bourns_3296W_Vertical
SW22: SW_SPST; SPDT_KIT
U5: LF347; DIP-14_W7.62mm_LongPads
U11, U12, U13: LM741; DIP-8_W7.62mm_LongPads
U14: 4016; DIP-14_W7.62mm_LongPads

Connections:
+VSW: R78.2, U11.7 (V+), U12.7 (V+), U13.7 (V+), U14.14 (VDD); also elsewhere on the board
-VSW: RV13.2, U11.4 (V-), U12.4 (V-), U13.4 (V-), U14.7 (VSS); also elsewhere on the board
GND: R71.2, R74.2, RV14.1, RV15.1, U13.3 (+), U14.3; also elsewhere on the board
IC22_PIN_3: C16.1, R75.2, U5.14, U14.5; also elsewhere on the board
KEYBOARD_IC7_PIN_6: SW22.1 (A); also elsewhere on the board
unnamed: C15.2, R73.1, U11.2 (-)
unnamed: C16.2, RV15.3
unnamed: C17.1, R119.1, U13.6, U14.9
unnamed: C17.2, R76.1, U13.2 (-), U14.8
unnamed: R70.1, R72.2, R76.2, SW22.2 (B)
unnamed: R70.2, R71.1, U11.3 (+)
unnamed: R72.1, R73.2, U14.4
unnamed: R74.1, R75.1, U5.12 (+)
unnamed: R77.2, U12.6
unnamed: R78.1, RV14.3
unnamed: R150.1, RV14.2
unnamed: R79.2, R150.2, U12.3 (+)
unnamed: RV13.1, U11.1 (NULL)
unnamed: RV13.3, U11.5 (NULL)
unnamed: RV15.2, U14.6
TO_VCO1_R79: R79.1; also elsewhere on the board
VCO1_SAW1: C15.1, U5.13 (-), U11.6, U12.2 (-); also elsewhere on the board
VCO1_SAW2: R119.2; also elsewhere on the board
VCO1_SQR: R77.1; also elsewhere on the board

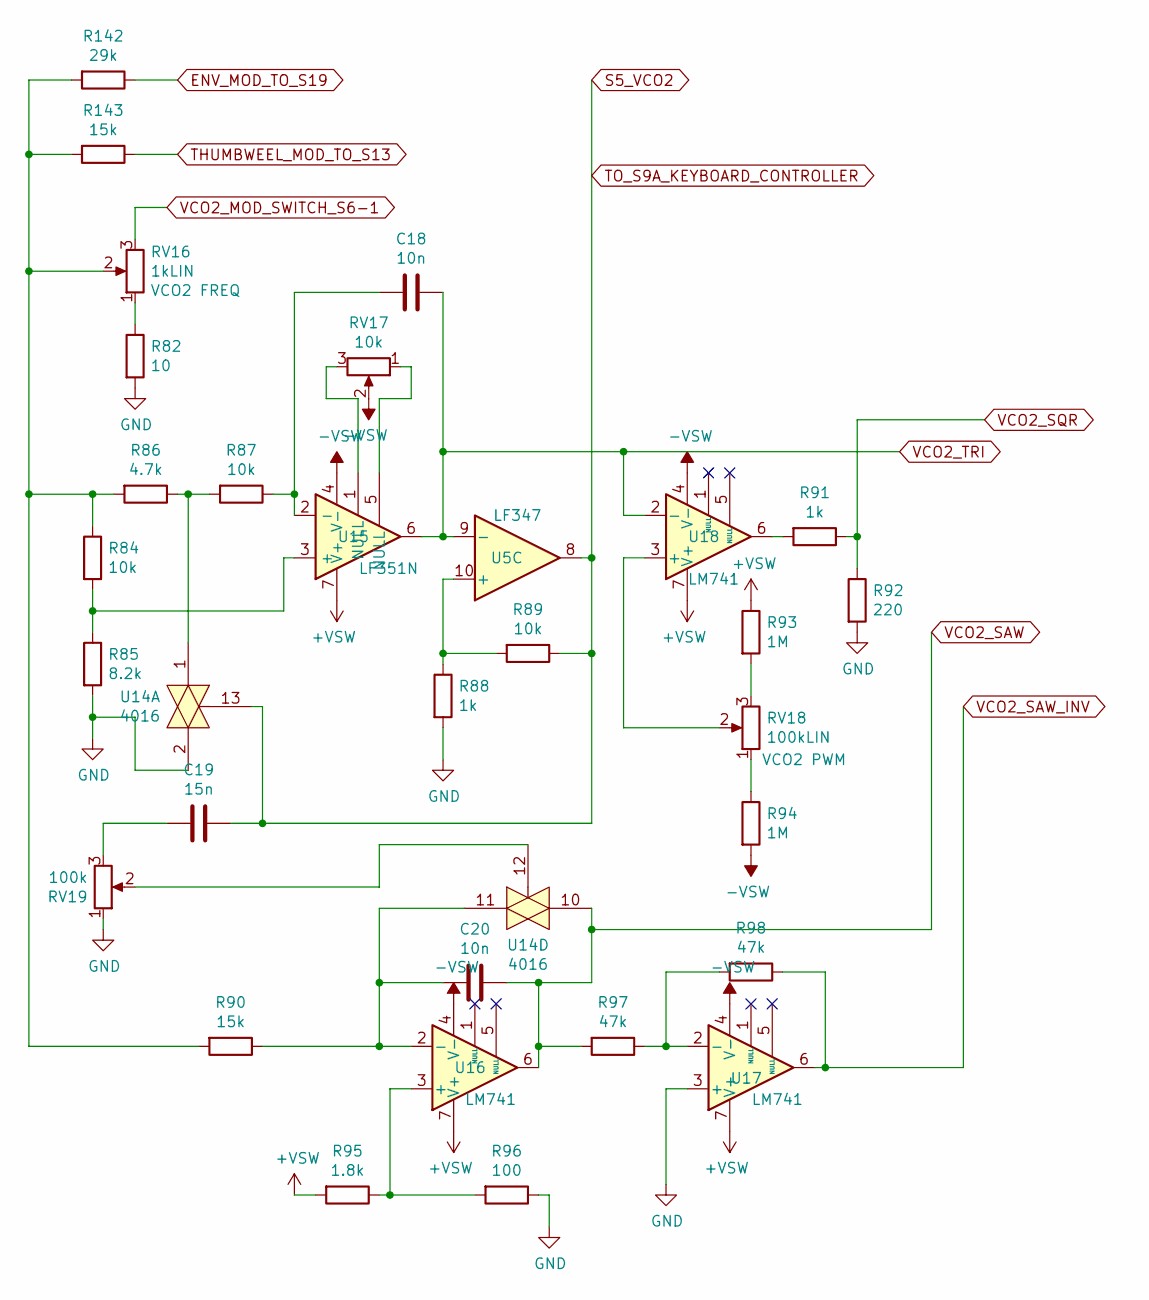
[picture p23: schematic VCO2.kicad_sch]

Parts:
C18, C20: 10n; C_Rect_L7.2mm_W2.5mm_P5.00mm_FKS2_FKP2_MKS2_MKP2
C19: 15n; C_Rect_L7.2mm_W3.5mm_P5.00mm_FKS2_FKP2_MKS2_MKP2
R82: 10; R_Axial_DIN0207_L6.3mm_D2.5mm_P10.16mm_Horizontal
R84, R87, R89: 10k; R_Axial_DIN0207_L6.3mm_D2.5mm_P10.16mm_Horizontal
R85: 8.2k; R_Axial_DIN0207_L6.3mm_D2.5mm_P10.16mm_Horizontal
R86: 4.7k; R_Axial_DIN0207_L6.3mm_D2.5mm_P10.16mm_Horizontal
R88, R91: 1k; R_Axial_DIN0207_L6.3mm_D2.5mm_P10.16mm_Horizontal
R90, R143: 15k; R_Axial_DIN0207_L6.3mm_D2.5mm_P10.16mm_Horizontal
R92: 220; R_Axial_DIN0207_L6.3mm_D2.5mm_P10.16mm_Horizontal
R93, R94: 1M; R_Axial_DIN0207_L6.3mm_D2.5mm_P10.16mm_Horizontal
R95: 1.8k; R_Axial_DIN0207_L6.3mm_D2.5mm_P10.16mm_Horizontal
R96: 100; R_Axial_DIN0207_L6.3mm_D2.5mm_P10.16mm_Horizontal
R97, R98: 47k; R_Axial_DIN0207_L6.3mm_D2.5mm_P10.16mm_Horizontal
R142: 29k; R_Axial_DIN0207_L6.3mm_D2.5mm_P10.16mm_Horizontal
RV16: 1kLIN; Pot_16mm_NoDet_RV16AF-4A
RV17: 10k; Potentiometer_Bourns_3296W_Vertical
RV18: 100kLIN; Pot_16mm_NoDet_RV16AF-4A
RV19: 100k; Potentiometer_Bourns_3296W_Vertical
U5: LF347; DIP-14_W7.62mm_LongPads
U14: 4016; DIP-14_W7.62mm_LongPads
U15: LF351N; DIP-8_W7.62mm_LongPads
U16, U17, U18: LM741; DIP-8_W7.62mm_LongPads

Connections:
+VSW: R93.1, R95.2, U15.7 (V+), U16.7 (V+), U17.7 (V+), U18.7 (V+); also elsewhere on the board
-VSW: R94.2, RV17.2, U15.4 (V-), U16.4 (V-), U17.4 (V-), U18.4 (V-); also elsewhere on the board
ENV_MOD_TO_S19: R142.1; also elsewhere on the board
GND: R82.2, R85.2, R88.2, R92.2, R96.1, RV19.1, U14.2, U17.3 (+); also elsewhere on the board
unnamed: C18.2, R87.1, U15.2 (-)
unnamed: C19.2, RV19.3
unnamed: C20.2, R90.1, U14.11, U16.2 (-)
unnamed: R82.1, RV16.1
unnamed: R84.2, R85.1, U15.3 (+)
unnamed: R86.1, R87.2, U14.1
unnamed: R88.1, R89.2, U5.10 (+)
unnamed: R91.2, U18.6
unnamed: R93.2, RV18.3
unnamed: R94.1, RV18.1
unnamed: R95.1, R96.2, U16.3 (+)
unnamed: R97.1, R98.2, U17.2 (-)
unnamed: R84.1, R86.2, R90.2, R142.2, R143.2, RV16.2
unnamed: RV17.1, U15.5 (NULL)
unnamed: RV17.3, U15.1 (NULL)
unnamed: RV18.2, U18.3 (+)
unnamed: RV19.2, U14.12
S5_VCO2: C19.1, R89.1, U5.8, U14.13; also elsewhere on the board
THUMBWEEL_MOD_TO_S13: R143.1; also elsewhere on the board
TO_VCA_C27: C18.1, U5.9 (-), U15.6, U18.2 (-); also elsewhere on the board
VCO2_MOD_SWITCH_S6-1: RV16.3; also elsewhere on the board
VCO2_SAW: C20.1, R97.2, U14.10, U16.6; also elsewhere on the board
VCO2_SAW_INV: R98.1, U17.6; also elsewhere on the board
VCO2_SQR: R91.1, R92.1; also elsewhere on the board

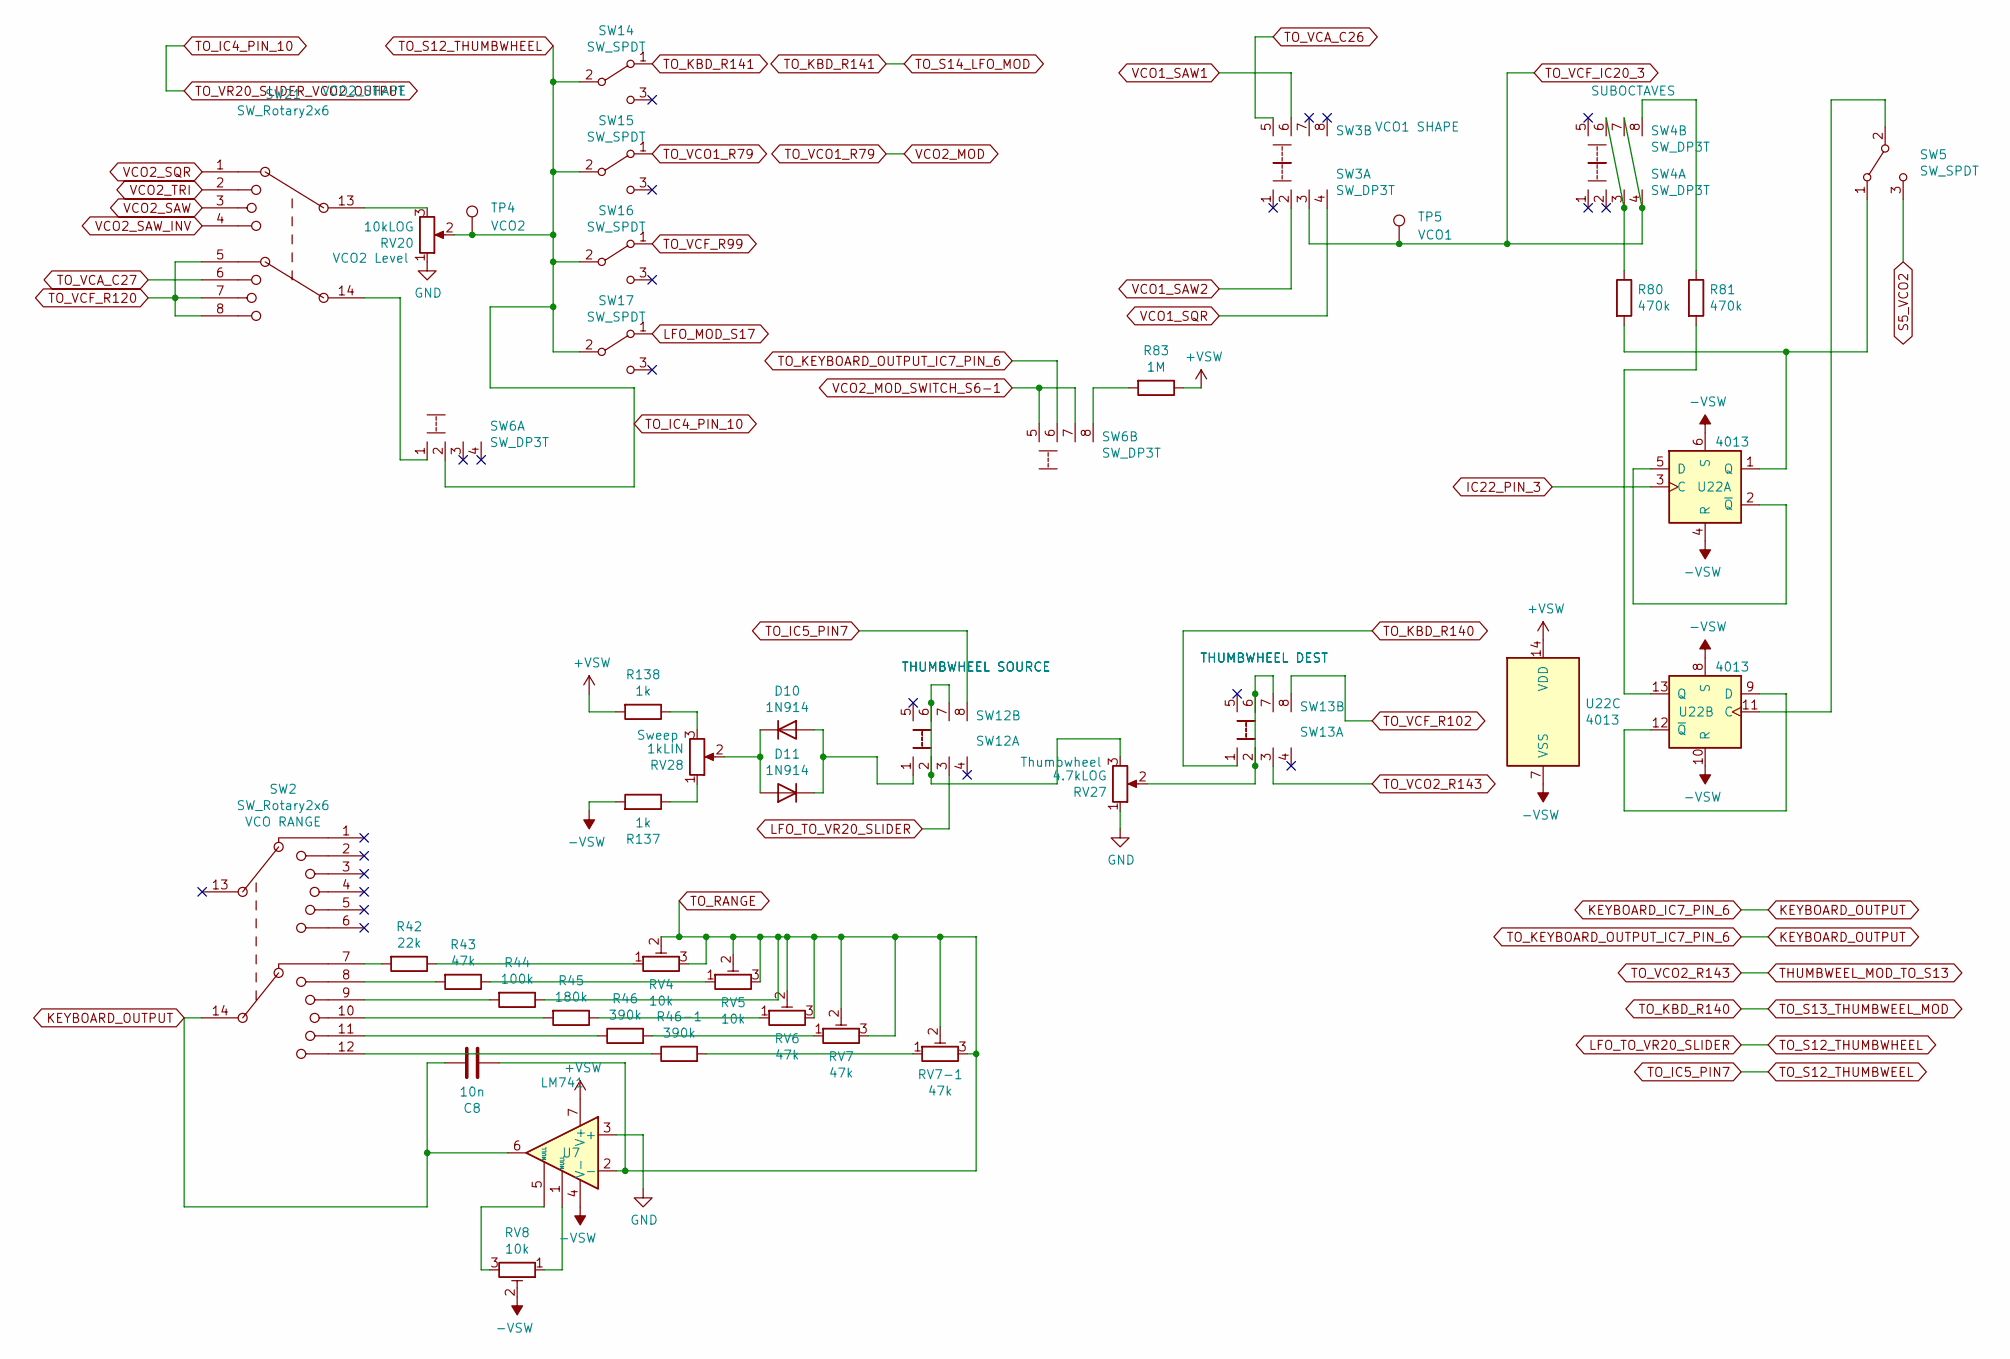
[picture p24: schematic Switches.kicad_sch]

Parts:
C8: 10n; C_Rect_L7.2mm_W2.5mm_P5.00mm_FKS2_FKP2_MKS2_MKP2
D10, D11: 1N914; D_DO-35_SOD27_P7.62mm_Horizontal
R42: 22k; R_Axial_DIN0207_L6.3mm_D2.5mm_P10.16mm_Horizontal
R43: 47k; R_Axial_DIN0207_L6.3mm_D2.5mm_P10.16mm_Horizontal
R44: 100k; R_Axial_DIN0207_L6.3mm_D2.5mm_P10.16mm_Horizontal
R45: 180k; R_Axial_DIN0207_L6.3mm_D2.5mm_P10.16mm_Horizontal
R46, R46-1: 390k; R_Axial_DIN0207_L6.3mm_D2.5mm_P10.16mm_Horizontal
R80, R81: 470k; R_Axial_DIN0207_L6.3mm_D2.5mm_P10.16mm_Horizontal
R83: 1M; R_Axial_DIN0207_L6.3mm_D2.5mm_P10.16mm_Horizontal
R137, R138: 1k; R_Axial_DIN0207_L6.3mm_D2.5mm_P10.16mm_Horizontal
RV4, RV5, RV8: 10k; Potentiometer_Bourns_3296W_Vertical
RV6, RV7, RV7-1: 47k; Potentiometer_Bourns_3296W_Vertical
RV20: 10kLOG; Pot_16mm_NoDet_RV16AF-4A
RV27: 4.7kLOG; Potentiometer_Bourns_PTV09A-2_Vertical
RV28: 1kLIN; Pot_16mm_NoDet_RV16AF-4A
SW2: SW_Rotary2x6; SR2511F-0206-(L)K0A-C9-S-3
SW3, SW4, SW6: SW_DP3T; 11-SS-23-832C
SW5, SW14, SW15, SW16, SW17: SW_SPDT; 11-SS-22-701C
SW12: THUMBWHEEL SOURCE; 11-SS-23-832C
SW13: THUMBWHEEL DEST; 11-SS-23-832C
SW21: SW_Rotary2x6; SR2511F-0204-(L)K0A-C9-S-3
TP4: VCO2; TestPoint_Pad_D2.0mm
TP5: VCO1; TestPoint_Pad_D2.0mm
U7: LM741; DIP-8_W7.62mm_LongPads
U22: 4013; DIP-14_W7.62mm_LongPads

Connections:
+VSW: R83.1, R138.2, U7.7 (V+), U22.14 (VDD); also elsewhere on the board
-VSW: R137.2, RV8.2, U7.4 (V-), U22.4 (R), U22.6 (S), U22.7 (VSS), U22.8 (S), U22.10 (R); also elsewhere on the board
GND: RV20.1, RV27.1, U7.3 (+); also elsewhere on the board
IC22_PIN_3: U22.3 (C); also elsewhere on the board
KEYBOARD_IC7_PIN_6: C8.1, SW2.14, SW6.6, U7.6; also elsewhere on the board
LFO_MOD_S16: SW16.1 (A); also elsewhere on the board
LFO_MOD_S17: SW17.1 (A); also elsewhere on the board
LFO_TO_VR20_SLIDER: RV20.2, SW6.2, SW12.3, SW14.2 (B), SW15.2 (B), SW16.2 (B), SW17.2 (B), TP4.1; also elsewhere on the board
unnamed: D10.1 (K), D11.2 (A), RV28.2
unnamed: D10.2 (A), D11.1 (K), SW12.1
unnamed: R42.1, RV4.1
unnamed: R42.2, SW2.7
unnamed: R43.1, RV5.1
unnamed: R43.2, SW2.8
unnamed: R44.2, SW2.9
unnamed: R45.1, RV6.1
unnamed: R45.2, SW2.10
unnamed: R46-1.1, SW2.12
unnamed: R46-1.2, RV7-1.1
unnamed: R46.1, SW2.11
unnamed: R46.2, RV7.1
unnamed: R80.1, SW4.3, SW4.6
unnamed: R80.2, SW5.1 (A), U22.1 (Q)
unnamed: R81.1, SW4.8
unnamed: R81.2, U22.13 (Q)
unnamed: R83.2, SW6.8
unnamed: R137.1, RV28.1
unnamed: R138.1, RV28.3
unnamed: RV8.1, U7.1 (NULL)
unnamed: RV8.3, U7.5 (NULL)
unnamed: RV20.3, SW21.13
unnamed: RV27.2, SW13.2, SW13.6, SW13.7
unnamed: RV27.3, SW12.2, SW12.6, SW12.7
unnamed: SW5.2 (B), U22.11 (C)
unnamed: SW6.1, SW21.14
unnamed: U22.2 (~Q), U22.5 (D)
unnamed: U22.9 (D), U22.12 (~Q)
S5_VCO2: SW5.3 (C); also elsewhere on the board
THUMBWEEL_MOD: SW13.8; also elsewhere on the board
THUMBWEEL_MOD_TO_S13: SW13.3; also elsewhere on the board
TO_IC5_PIN7: SW12.8; also elsewhere on the board
TO_KBD_R140: SW13.1; also elsewhere on the board
TO_KBD_R141: SW14.1 (A); also elsewhere on the board
TO_RANGE: C8.2, R44.1, RV4.2, RV4.3, RV5.2, RV5.3, RV6.2, RV6.3, RV7.2, RV7.3, RV7-1.2, RV7-1.3, U7.2 (-); also elsewhere on the board
TO_VCA_C26: SW3.5; also elsewhere on the board
TO_VCA_C27: SW21.2, SW21.6; also elsewhere on the board
TO_VCF_IC20_3: SW3.3, SW4.4, SW4.7, TP5.1; also elsewhere on the board
TO_VCF_R120: SW21.5, SW21.7, SW21.8; also elsewhere on the board
TO_VCO1_R79: SW15.1 (A); also elsewhere on the board
VCO1_SAW1: SW3.6; also elsewhere on the board
VCO1_SAW2: SW3.2; also elsewhere on the board
VCO1_SQR: SW3.4; also elsewhere on the board
VCO2_MOD_SWITCH_S6-1: SW6.5, SW6.7; also elsewhere on the board
VCO2_SAW: SW21.3; also elsewhere on the board
VCO2_SAW_INV: SW21.4; also elsewhere on the board
VCO2_SQR: SW21.1; also elsewhere on the board

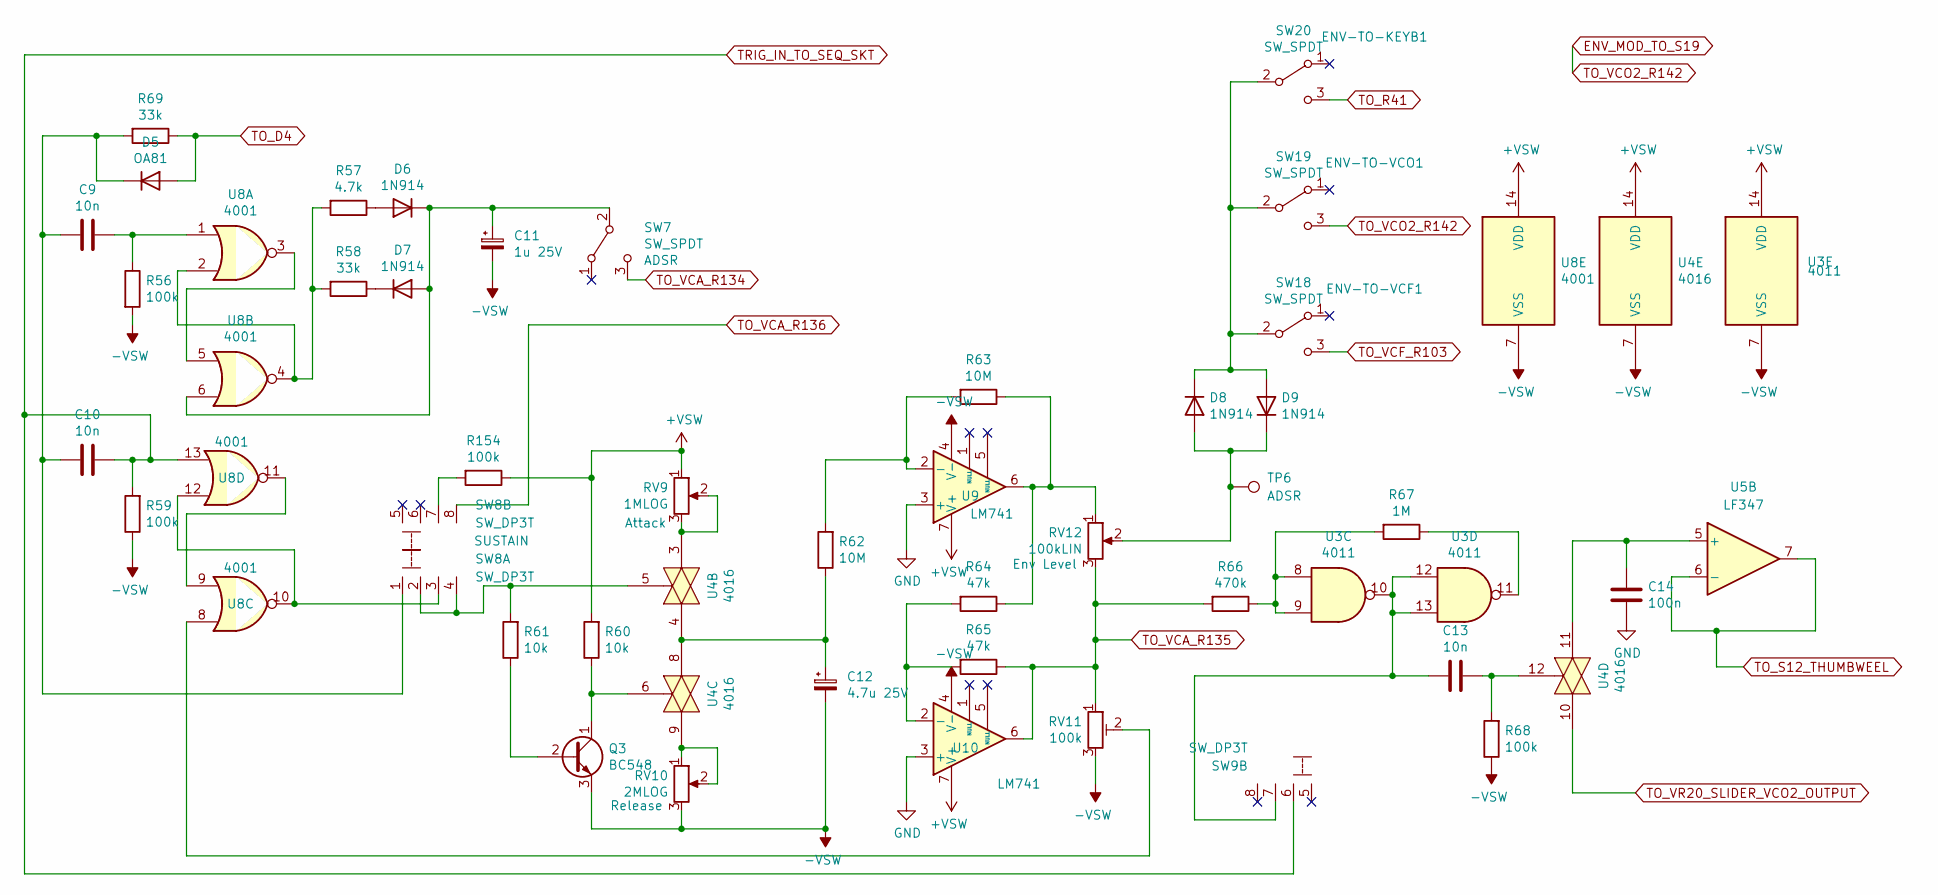
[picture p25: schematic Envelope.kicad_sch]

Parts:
C9, C10, C13: 10n; C_Rect_L7.2mm_W2.5mm_P5.00mm_FKS2_FKP2_MKS2_MKP2
C11: 1u 25V; CP_Radial_D5.0mm_P2.50mm
C12: 4.7u 25V; CP_Radial_D5.0mm_P2.50mm
C14: 100n; C_Rect_L7.2mm_W2.5mm_P5.00mm_FKS2_FKP2_MKS2_MKP2
D5: OA81; D_A-405_P10.16mm_Horizontal
D6, D7, D8, D9: 1N914; D_DO-35_SOD27_P7.62mm_Horizontal
Q3: BC548; TO-92L_Inline_Wide
R56, R59, R68, R154: 100k; R_Axial_DIN0207_L6.3mm_D2.5mm_P10.16mm_Horizontal
R57: 4.7k; R_Axial_DIN0207_L6.3mm_D2.5mm_P10.16mm_Horizontal
R58, R69: 33k; R_Axial_DIN0207_L6.3mm_D2.5mm_P10.16mm_Horizontal
R60, R61: 10k; R_Axial_DIN0207_L6.3mm_D2.5mm_P10.16mm_Horizontal
R62, R63: 10M; R_Axial_DIN0207_L6.3mm_D2.5mm_P10.16mm_Horizontal
R64, R65: 47k; R_Axial_DIN0207_L6.3mm_D2.5mm_P10.16mm_Horizontal
R66: 470k; R_Axial_DIN0207_L6.3mm_D2.5mm_P10.16mm_Horizontal
R67: 1M; R_Axial_DIN0207_L6.3mm_D2.5mm_P10.16mm_Horizontal
RV9: 1MLOG; Pot_16mm_NoDet_RV16AF-4A
RV10: 2MLOG; Pot_16mm_NoDet_RV16AF-4A
RV11: 100k; Potentiometer_Bourns_3296W_Vertical
RV12: 100kLIN; Pot_16mm_NoDet_RV16AF-4A
SW7, SW18, SW19, SW20: SW_SPDT; 11-SS-22-701C
SW8, SW9: SW_DP3T; 11-SS-23-832C
TP6: ADSR; TestPoint_Pad_D2.0mm
U3: 4011; DIP-14_W7.62mm_LongPads
U4: 4016; DIP-14_W7.62mm_LongPads
U5: LF347; DIP-14_W7.62mm_LongPads
U8: 4001; DIP-14_W7.62mm_LongPads
U9, U10: LM741; DIP-8_W7.62mm_LongPads

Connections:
+VSW: R60.2, R154.1, RV9.1, U3.14 (VDD), U4.14 (VDD), U8.14 (VDD), U9.7 (V+), U10.7 (V+); also elsewhere on the board
-VSW: C11.2, C12.2, Q3.3 (E), R56.2, R59.1, R68.1, RV10.3, RV11.3, U3.7 (VSS), U4.7 (VSS), U8.7 (VSS), U9.4 (V-), U10.4 (V-); also elsewhere on the board
ADSR: SW7.3 (C); also elsewhere on the board
ENVELOPE: R65.1, R66.2, RV11.1, RV12.3, U10.6; also elsewhere on the board
ENV_MOD: SW18.3 (C); also elsewhere on the board
ENV_MOD_TO_S19: SW19.3 (C); also elsewhere on the board
GND: C14.2, U9.3 (+), U10.3 (+); also elsewhere on the board
LFO_TO_VR20_SLIDER: U4.10; also elsewhere on the board
unnamed: C9.1, R56.1, U8.1
unnamed: C9.2, C10.2, D5.1 (K), R69.2, SW8.1
unnamed: C11.1, D6.1 (K), D7.2 (A), SW7.2 (B), U8.6
unnamed: C12.1, R62.1, U4.4, U4.8
unnamed: C13.1, R68.2, U4.12
unnamed: C13.2, SW9.7, U3.10, U3.12, U3.13
unnamed: C14.1, U4.11, U5.5 (+)
unnamed: D6.2 (A), R57.1
unnamed: D7.1 (K), R58.1
unnamed: D8.1 (K), D9.2 (A), SW18.2 (B), SW19.2 (B), SW20.2 (B)
unnamed: D8.2 (A), D9.1 (K), RV12.2, TP6.1
unnamed: Q3.1 (C), R60.1, U4.6
unnamed: Q3.2 (B), R61.1
unnamed: R57.2, R58.2, U8.2, U8.4
unnamed: R61.2, SW8.2, SW8.4, U4.5
unnamed: R62.2, R63.2, U9.2 (-)
unnamed: R63.1, R64.1, RV12.1, U9.6
unnamed: R64.2, R65.2, U10.2 (-)
unnamed: R66.1, R67.2, U3.8, U3.9
unnamed: R67.1, U3.11
unnamed: R154.2, SW8.7
unnamed: RV9.2, RV9.3, U4.3
unnamed: RV10.1, RV10.2, U4.9
unnamed: RV11.2, U8.8
unnamed: SW8.3, U8.10, U8.12
unnamed: U8.3, U8.5
unnamed: U8.9, U8.11
TO_D4: D5.2 (A), R69.1; also elsewhere on the board
TO_IC5_PIN7: U5.6 (-), U5.7; also elsewhere on the board
TO_R41: SW20.3 (C); also elsewhere on the board
TO_VCA_R136: SW8.8; also elsewhere on the board
TRIG_IN_TO_SEQ_SKT: C10.1, R59.2, SW9.6, U8.13; also elsewhere on the board

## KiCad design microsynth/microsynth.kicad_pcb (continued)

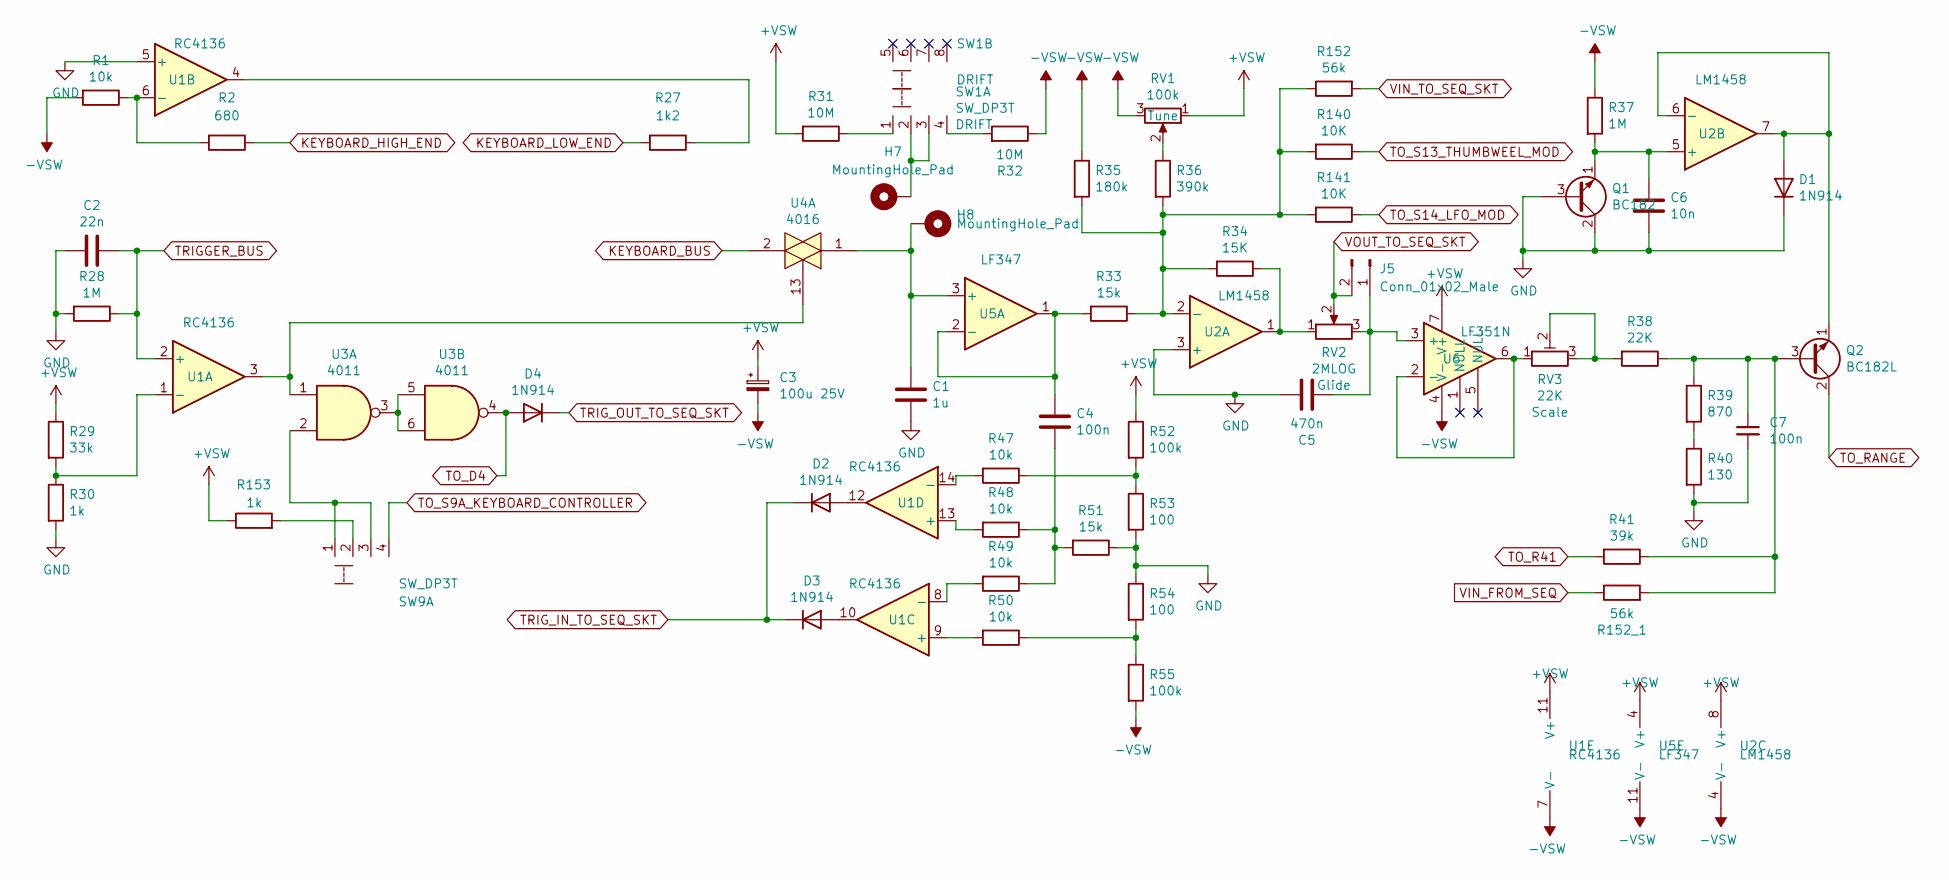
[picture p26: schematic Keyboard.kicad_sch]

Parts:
C1: 1u; C_Rect_L7.2mm_W7.2mm_P5.00mm_FKS2_FKP2_MKS2_MKP2
C2: 22n; C_Rect_L7.2mm_W2.5mm_P5.00mm_FKS2_FKP2_MKS2_MKP2
C3: 100u 25V; CP_Radial_D5.0mm_P2.50mm
C4, C7: 100n; C_Rect_L7.2mm_W2.5mm_P5.00mm_FKS2_FKP2_MKS2_MKP2
C5: 470n; C_Rect_L7.2mm_W4.5mm_P5.00mm_FKS2_FKP2_MKS2_MKP2
C6: 10n; C_Rect_L7.2mm_W2.5mm_P5.00mm_FKS2_FKP2_MKS2_MKP2
D1, D2, D3, D4: 1N914; D_DO-35_SOD27_P7.62mm_Horizontal
H7, H8: MountingHole_Pad; PinHeader_1x01_P2.54mm_Vertical
J5: Conn_01x02_Male; PinHeader_1x02_P2.54mm_Vertical
Q1: BC182; TO-92L_Inline_Wide
Q2: BC182L; TO-92L_Inline_Wide
R1, R47, R48, R49, R50: 10k; R_Axial_DIN0207_L6.3mm_D2.5mm_P10.16mm_Horizontal
R2: 680; R_Axial_DIN0207_L6.3mm_D2.5mm_P10.16mm_Horizontal
R27: 1k2; R_Axial_DIN0207_L6.3mm_D2.5mm_P10.16mm_Horizontal
R28, R37: 1M; R_Axial_DIN0207_L6.3mm_D2.5mm_P10.16mm_Horizontal
R29: 33k; R_Axial_DIN0207_L6.3mm_D2.5mm_P10.16mm_Horizontal
R30, R153: 1k; R_Axial_DIN0207_L6.3mm_D2.5mm_P10.16mm_Horizontal
R31, R32: 10M; R_Axial_DIN0207_L6.3mm_D2.5mm_P10.16mm_Horizontal
R33, R51: 15k; R_Axial_DIN0207_L6.3mm_D2.5mm_P10.16mm_Horizontal
R34: 15K; R_Axial_DIN0207_L6.3mm_D2.5mm_P10.16mm_Horizontal
R35: 180k; R_Axial_DIN0207_L6.3mm_D2.5mm_P10.16mm_Horizontal
R36: 390k; R_Axial_DIN0207_L6.3mm_D2.5mm_P10.16mm_Horizontal
R38: 22K; R_Axial_DIN0207_L6.3mm_D2.5mm_P10.16mm_Horizontal
R39: 870; R_Axial_DIN0207_L6.3mm_D2.5mm_P10.16mm_Horizontal
R40: 130; R_Axial_DIN0207_L6.3mm_D2.5mm_P10.16mm_Horizontal
R41: 39k; R_Axial_DIN0207_L6.3mm_D2.5mm_P10.16mm_Horizontal
R52, R55: 100k; R_Axial_DIN0207_L6.3mm_D2.5mm_P10.16mm_Horizontal
R53, R54: 100; R_Axial_DIN0207_L6.3mm_D2.5mm_P10.16mm_Horizontal
R140, R141: 10K; R_Axial_DIN0207_L6.3mm_D2.5mm_P10.16mm_Horizontal
R152, R152_1: 56k; R_Axial_DIN0207_L6.3mm_D2.5mm_P10.16mm_Horizontal
RV1: 100k; Potentiometer_Bourns_3296W_Vertical
RV2: 2MLOG; Pot_16mm_NoDet_RV16AF-4A
RV3: 22K; Potentiometer_Bourns_3296W_Vertical
SW1: SW_DP3T; 11-SS-23-832C
SW9: TRIGGER; 11-SS-23-832C
U1: RC4136; DIP-14_W7.62mm_LongPads
U2: LM1458; DIP-8_W7.62mm_LongPads
U3: 4011; DIP-14_W7.62mm_LongPads
U4: 4016; DIP-14_W7.62mm_LongPads
U5: LF347; DIP-14_W7.62mm_LongPads
U6: LF351N; DIP-8_W7.62mm_LongPads

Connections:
+VSW: C3.1, R29.1, R31.2, R52.1, R153.1, RV1.1, U1.11 (V+), U2.8 (V+), U5.4 (V+), U6.7 (V+); also elsewhere on the board
-VSW: C3.2, R1.2, R32.1, R35.1, R37.1, R55.2, RV1.3, U1.7 (V-), U2.4 (V-), U5.11 (V-), U6.4 (V-); also elsewhere on the board
GND: C1.2, C2.2, C5.2, C6.2, C7.2, D1.1 (K), Q1.2 (C), Q1.3 (B), R28.2, R30.2, R40.2, R51.1, R53.2, R54.1, U1.5 (+), U2.3 (+); also elsewhere on the board
KEYBOARD_BUS: U4.2; also elsewhere on the board
KEYBOARD_HIGH_END: R2.1; also elsewhere on the board
KEYBOARD_LOW_END: R27.2; also elsewhere on the board
unnamed: C1.1, H8.1, U4.1, U5.3 (+)
unnamed: C4.1, R33.2, U5.1, U5.2 (-)
unnamed: C4.2, R48.1, R49.1, R51.2
unnamed: C5.1, J5.1, RV2.3, U6.3 (+)
unnamed: C6.1, Q1.1 (E), R37.2, U2.5 (+)
unnamed: C7.1, Q2.3 (B), R38.1, R39.1, R41.1, R152_1.2
unnamed: D1.2 (A), Q2.1 (E), U2.6 (-), U2.7
unnamed: D2.2 (A), U1.12
unnamed: D3.2 (A), U1.10
unnamed: H7.1, SW1.2, SW1.3
unnamed: R1.1, R2.2, U1.6 (-)
unnamed: R27.1, U1.4
unnamed: R29.2, R30.1, U1.1 (-)
unnamed: R31.1, SW1.1
unnamed: R32.2, SW1.4
unnamed: R34.1, RV2.1, U2.1
unnamed: R36.1, RV1.2
unnamed: R38.2, RV3.2, RV3.3
unnamed: R39.2, R40.1
unnamed: R47.1, R52.2, R53.1
unnamed: R47.2, U1.14 (-)
unnamed: R48.2, U1.13 (+)
unnamed: R49.2, U1.8 (-)
unnamed: R50.1, R54.2, R55.1
unnamed: R50.2, U1.9 (+)
unnamed: R33.1, R34.2, R35.2, R36.2, R140.2, R141.2, R152.1, U2.2 (-)
unnamed: R153.2, SW9.2
unnamed: RV3.1, U6.2 (-), U6.6
unnamed: SW9.1, SW9.3, U3.2
unnamed: U1.3, U3.1, U4.13
unnamed: U3.3, U3.5, U3.6
S5_VCO2: SW9.4; also elsewhere on the board
TO_D4: D4.2 (A), U3.4; also elsewhere on the board
TO_KBD_R140: R140.1; also elsewhere on the board
TO_KBD_R141: R141.1; also elsewhere on the board
TO_R41: R41.2; also elsewhere on the board
TO_RANGE: Q2.2 (C); also elsewhere on the board
TRIGGER_BUS: C2.1, R28.1, U1.2 (+); also elsewhere on the board
TRIG_IN_TO_SEQ_SKT: D2.1 (K), D3.1 (K); also elsewhere on the board
TRIG_OUT_TO_SEQ_SKT: D4.1 (K); also elsewhere on the board
VIN_FROM_SEQ: R152_1.1; also elsewhere on the board
VIN_TO_SEQ_SKT: R152.2; also elsewhere on the board
VOUT_TO_SEQ_SKT: J5.2, RV2.2; also elsewhere on the board

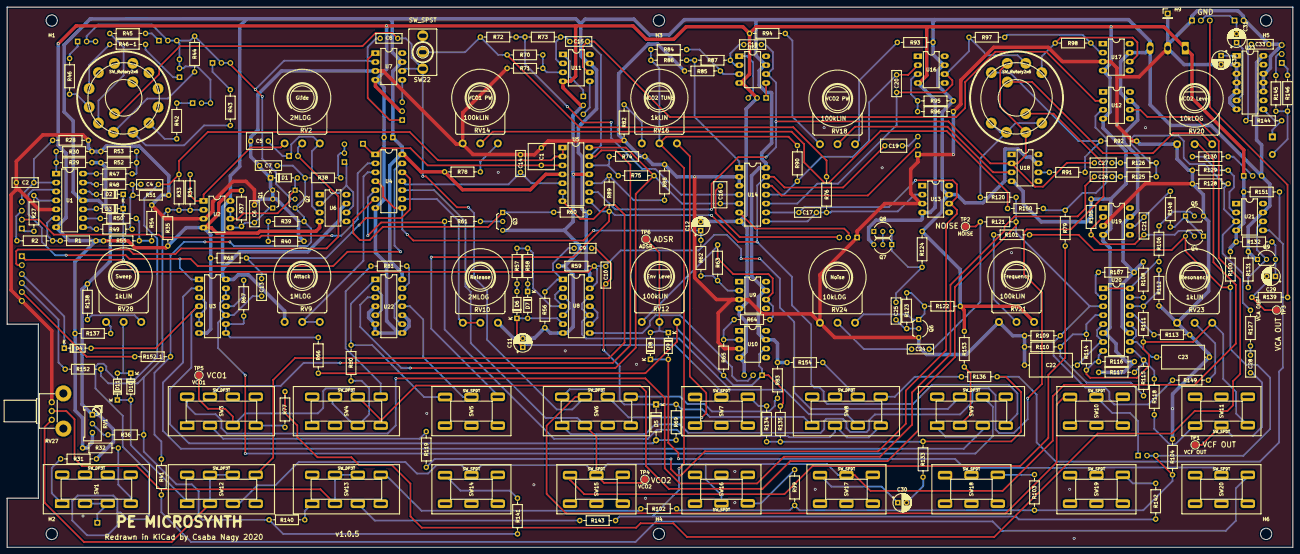
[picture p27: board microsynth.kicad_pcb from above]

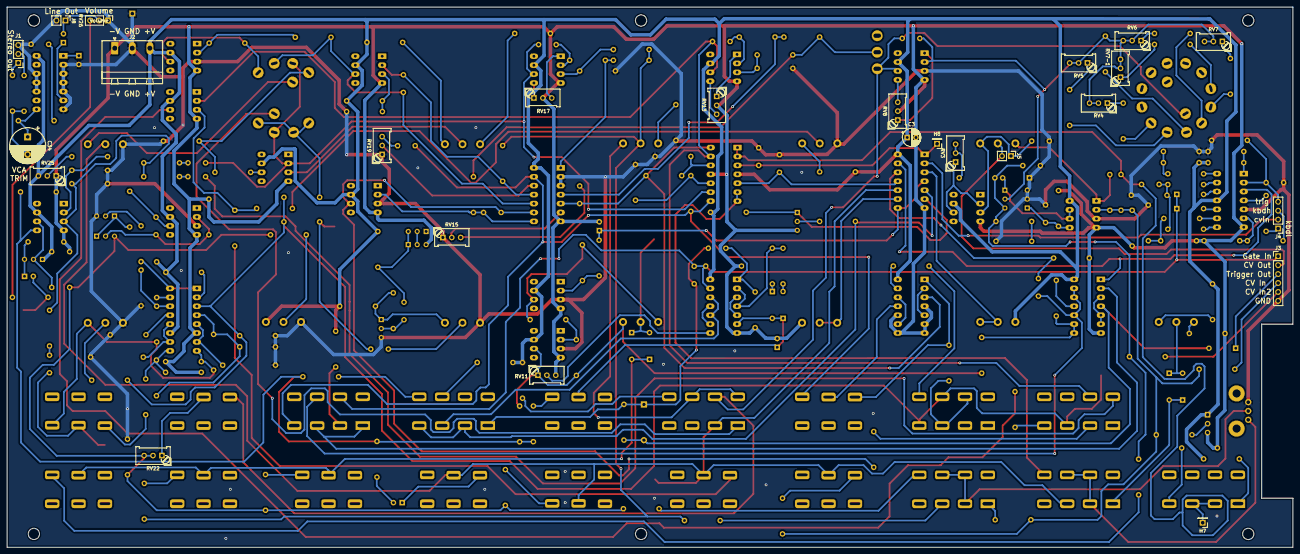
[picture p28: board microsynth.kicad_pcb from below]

Board: 2 copper layers, 365.8 x 153.7 mm, 280 parts (25 on the bottom side), 208 nets.

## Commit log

2020-04-01 Footprints 2
    [Envelope.sch, Keyboard.sch, VCA.sch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]
2020-04-01 Hacking together the footprints
    [Envelope.sch, Keyboard.sch, VCA.sch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]
2020-04-03 All components placed on PCB
    [Envelope.sch, Keyboard.sch, VCA.sch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]
2020-04-03 Add front panel design
    [pe-microsynth.dxf]
2020-04-03 Aligned switches and pots
    [microsynth.kicad_pcb, switches.sch]
2020-04-06 Laying out pcb
    [Envelope.sch, Keyboard.sch, VCA.sch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]
2020-04-08 Laying out pcb ...
    [Envelope.sch, Keyboard.sch, microsynth.kicad_pcb]
2020-04-17 Add 3d models
    [DP3T Slide Switch.step, G-1128S-1110_3D MODEL.stp, Rotary switch 3P4T.step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]
2020-04-17 Change switch footprints
    [Envelope.sch, Keyboard.sch, microsynth.kicad_pcb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]
2020-04-20 Move connectors to back
    [microsynth.kicad_pcb]
2020-04-22 Replacing dp3p switches 1.
    [microsynth.kicad_pcb]
2020-04-22 Replacing dp3p switches 2.
    [microsynth.kicad_pcb]
2020-04-25 Replacing SPDT switches
    [GF-624-6014_3D MODEL.stp, microsynth.kicad_pcb]
2020-04-26 Replace all SPDT switches
    [microsynth.kicad_pcb]
2020-04-26 Tidy up, 1 solder wire
    [microsynth.kicad_pcb]
2020-04-26 Tidy up, name switches, proper footprints for all trimmers
    [Envelope.sch, Keyboard.sch, VCO1.sch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]
2020-04-26 Replace switches in schematic, add extra octave to VCO
    [Keyboard.sch, microsynth.kicad_pcb, switches.sch]
2020-04-26 Update datasheet for SW2
    [switches.sch]
2020-04-28 Replace SW21 with 3p4t tayda
    [microsynth.kicad_pcb, switches.sch]
2020-04-29 Proper capacitor footprints
    [Envelope.sch, Keyboard.sch, VCA.sch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]
2020-04-30 Label pots
    [Keyboard.sch, VCO2.sch, microsynth.kicad_pcb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]
2020-05-03 Added pots datasheets, tidy up U9 U10 labels
    [Envelope.sch, microsynth.kicad_pcb]
2020-05-03 Reroute a long track
    [microsynth.kicad_pcb]
2020-05-03 Add new V input
    [Keyboard.sch, power.sch]
2020-05-03 Add VCO2 on/off toggle, faceplace 3d, and new faceplate version
    [RS-PRO Schalter v5.step, microsynth.kicad_pcb, pe-microsynthv2.dxf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]
2020-05-03 Add thumbwheel scad file
    [thumbwheel.scad]
2020-05-04 Front panel v3
    [pe-microsynthv3.dxf, pe-microsynthv3.stp]
2020-05-04 Text on pcb and local footprints
    [microsynth.kicad_pcb]
2020-05-04 Add new front panel to 3d view
    [microsynth.kicad_pcb]
2020-05-06 gitignore and thumbwheel update
    [thumbwheel.scad]
2020-05-06 Update thumbwheel to parametric
    [thumbwheel.scad]
2020-05-09 New 3d models
    [ALPS RK09L v3.step, SS-22-701C.scad, SS-23-832C.scad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]
2020-05-09 Clean up repo
    [Envelope.sch, Keyboard.sch, VCO1.sch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]
2020-05-10 Tidy up layout
    [microsynth.kicad_pcb]
2020-05-10 More layout/repo tidy up
    [microsynth.kicad_pcb, pe-microsynthv3.stp]
2020-05-10 Replace front panel
    [microsynth.kicad_pcb, pe-microsynthv3.dxf]
2020-05-10 Replace thumbwheel and cleanup
    [microsynth.kicad_pcb, pe-microsynthv3.dxf, pe-microsynthv3.stp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]
2020-05-10 Front panel update
    [microsynth.kicad_pcb, pe-microsynthv3.dxf]
2020-05-13 Replace dodgy parts 1458, 4136 & LF351s
    [Envelope.sch, Keyboard.sch, VCA.sch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]
2020-05-14 Proper mounting holes
    [microsynth.kicad_pcb, power.sch]
2020-05-17 Replace DP3T footprint, proper wire pads
    [Envelope.sch, Keyboard.sch, microsynth.kicad_pcb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]
2020-05-17 Add tayda slide switch datasheets (DPDT & DP3T)
2020-05-17 Add tayda rotary switch datasheet
2020-05-17 Add thumbwheel datasheet and 3d model
    [RK09K1110B1V.STEP]
2020-05-17 Replace all switches with tayda footprint
    [microsynth.kicad_pcb]
2020-05-21 Consolidate switches
    [Envelope.sch, Keyboard.sch, microsynth.kicad_pcb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]
2020-05-26 Consolidate all(?) switches
    [Envelope.sch, Keyboard.sch, VCO1.sch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]
2020-06-02 Update tayda switch footprints
2020-06-04 Update tayda rotary switch footprints and layout
    [microsynth.kicad_pcb, switches.sch]
2020-06-04 Adjust track widths
    [microsynth.kicad_pcb]
2020-06-04 Tidy up
    [microsynth.kicad_pcb]
2020-06-05 Copper fill GND
    [microsynth.kicad_pcb]
2020-06-05 Add tayda rotary switch footprints (again)
2020-06-07 Add test points
    [Envelope.sch, VCA.sch, microsynth.kicad_pcb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]
2020-06-25 Remove smd footprints, create and assign power/default tracks, tidy up ground planes
    [microsynth.kicad_pcb]
2020-06-25 More ground plane tidy ups
    [microsynth.kicad_pcb]
2020-08-01 Update switch footprints with bigger pads
    [microsynth.kicad_pcb]
2020-08-01 Update switch footprints with bigger pads again
    [microsynth.kicad_pcb]
2020-08-02 Improve layout
    [Keyboard.sch, microsynth.kicad_pcb]
2020-08-19 Add GND test point, add gnd to CV/Gate In/Out connector
    [microsynth.kicad_pcb, power.sch]
2020-08-23 Remove FPD exports
    [pe-microsynth.dxf, pe-microsynthv2.dxf, pe-microsynthv2.stp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]
2020-08-23 Update image links, label Tune pot
    [Keyboard.sch]
2020-08-24 Fix output amp
    [VCA.sch, microsynth.kicad_pcb]
2020-09-08 Put test point values to silkskreen
    [microsynth.kicad_pcb]
2020-09-09 Replace power connector with 4 pin molex p3.96
    [power.sch]
2020-09-09 Replace power connector, optimize layout around it
    [microsynth.kicad_pcb]
2020-09-09 Replace power connector (again) with a plug-in style, remove redundant global label
    [Envelope.sch, Keyboard.sch, microsynth.kicad_pcb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]
2020-09-15 Optimize layout around U1
    [microsynth.kicad_pcb]
2020-09-25 Optimise layout around output
    [microsynth.kicad_pcb]
2020-11-08 Add ground fills
    [microsynth.kicad_pcb]
2023-02-16 Update gitignore, ignore gerber outputs
2023-02-16 Not sure. Looks like stuff got moved around
    [microsynth.kicad_pcb]
2023-02-19 Upgrade to KiCad 7
    [Envelope.kicad_sch, Keyboard.kicad_sch, Power.kicad_sch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]
2023-05-29 Remove obsolete files
    [Envelope.sch, Keyboard.sch, VCA.sch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]
